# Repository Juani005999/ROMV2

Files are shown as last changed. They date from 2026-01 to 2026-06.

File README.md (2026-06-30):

# ROMV2 / SQM Lite

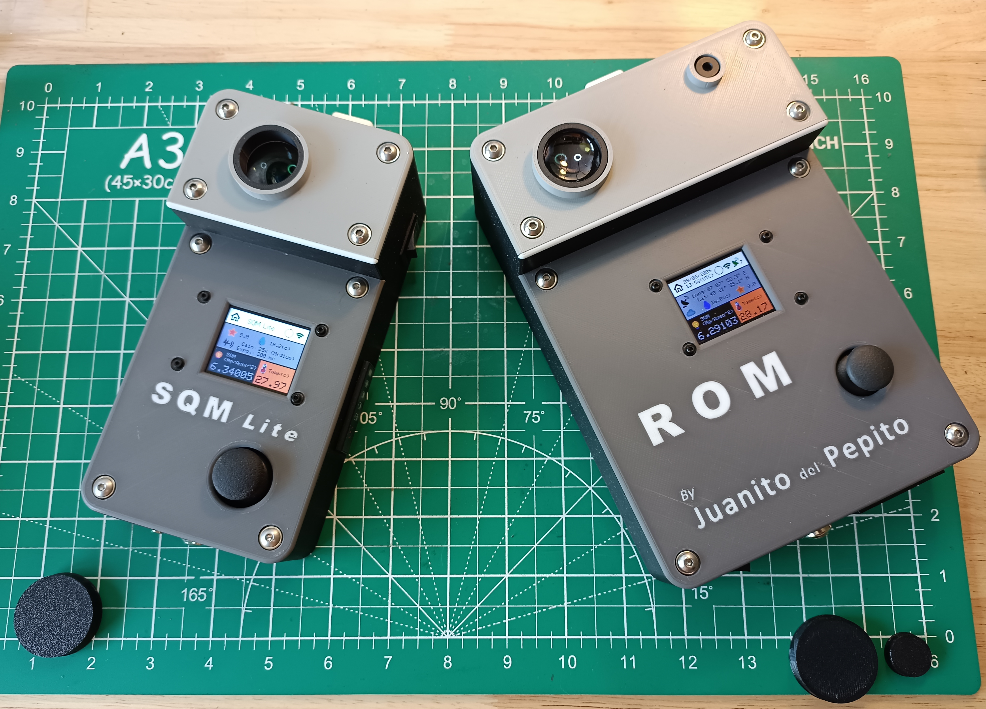
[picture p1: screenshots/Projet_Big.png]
ROM V2 et SQM Lite


## Sommaire
- [Description](#description)
    - [Fonctionnalités](#fonctionnalités)
    - [Modèles](#modèles)
        - [Fonctionnalités par modèle](#fonctionnalités-par-modèle)
        - [Écrans disponibles](#écrans-disponibles)
    - [Echelle de Bortle](#echelle-de-bortle)
- [Liste des pièces](#liste-des-pièces)
    - [Liste des pièces du ROMV2](#liste-des-pièces-du-romv2)
        - [Amazon](#amazon)
        - [Ali Express](#ali-express)
        - [Visserie & Divers](#visserie--divers)
    - [Liste des pièces du SQMLite](#liste-des-pièces-du-sqmlite)
        - [Amazon](#amazon-1)
        - [Ali Express](#ali-express-1)
        - [Visserie & Divers](#visserie--divers-1)
- [Montage](#montage)
    - [Montage du ROMV2](#montage-du-romv2)
        - [Breadboard](#breadboard)
        - [PCB](#pcb)
        - [ESP32](#esp32)
        - [Capteurs](#capteurs)
    - [Montage du SQMLite](#montage-du-sqmlite)
        - [Breadboard](#breadboard-1)
        - [PCB](#pcb-1)
        - [ESP32](#esp32-1)
        - [Capteurs](#capteurs-1)
    - [Boxes](#boxes)
    - [Optique du TSL2591](#optique-du-tsl2591)
- [Firmware](#firmware)
    - [Bibliothèques nécessaires à l'application](#bibliothèques-nécessaires-à-lapplication)
    - [Sélection de la carte](#sélection-de-la-carte)
    - [Paramètres de l'application dans Arduino IDE](#paramètres-de-lapplication-dans-arduino-ide)
    - [Configuration de l'application](#configuration-de-lapplication)
    - [Configuration de l'écran TFT ST7735](#configuration-de-lécran-tft-st7735)
    - [Implémentation](#implémentation)
    - [Mode \"Debug\"](#mode-debug)
- [Utilisation](#utilisation)
    - [Matériel (ROMV2)](#matériel-romv2)
    - [Matériel (SQMLite)](#matériel-sqmlite)
    - [Navigation](#navigation)
    - [Mise en veille](#mise-en-veille)
    - [Logiciel](#logiciel)
        - [En-tête (ROMV2)](#en-tête-romv2)
        - [En-tête (SQMLite)](#en-tête-sqmlite)
        - [Ecran d'accueil](#ecran-daccueil)
        - [Ecran Luminosité](#ecran-luminosité)
        - [Ecran Environnement](#ecran-environnement)
        - [Ecran Ir Température](#ecran-ir-température)
        - [Ecran Niveaux](#ecran-niveaux)
        - [Ecran GPS](#ecran-gps)
        - [Ecran de calibration du capteur de luminosité TSL2591](#ecran-de-calibration-du-capteur-de-luminosité-tsl2591)
- [Driver ASCOM](#driver-ascom)
    - [Installation](#installation)
    - [Détection du périphérique bluetooth dans Windows](#détection-du-périphérique-bluetooth-dans-windows)
    - [Utilisation dans NINA](#utilisation-dans-nina)
        - [Sélection du ROM V2 dans NINA](#sélection-du-rom-v2-dans-nina)
        - [Première utilisation dans NINA](#première-utilisation-dans-nina)
- [Retex](#retex)
- [Révisions](#révisions)

## Description
Le **ROMV2** est un Sky Quality Meter (SQM) DIY (Do It Yourself) contenant les composants suivant :
- TSL2591
- MLX90614
- BME280
- ADXL345
- GPS NEO 8M
- TFT ST7735

Le **SQMLite** est un Sky Quality Meter (SQM) DIY (Do It Yourself) contenant les composants suivant :
- TSL2591
- BME280
- TFT ST7735

Le **SQMLite** est une version à moindre coût, centrée sur la mesure de qualité du ciel (SQM / Bortle) et des conditions d'environnement, sans la partie état du ciel, niveau à bulle ni GPS.

<p align="right"><a href="#sommaire">Retour au sommaire</a></p>

### Fonctionnalités

- Lecture de la luminosité (full / ir / visible), calcul de la quantité de lux, du SQM et du Bortle.
- Lecture de la luminosité dans une tâche dédiée FreeRTOS s'exécutant en paralèlle sur le 2ème coeur de l'ESP 32.
- Correction thermique de la lecture de la luminosité avec la température ambiante.
- Moyenne mobile du lux sur 50 valeurs permettant de réduire l'incertitude mesurée. Calcul du SQM et du Bortle sur la moyenne mobile du lux.
- Possibilité de remise à zéro de la moyenne mobile.
- Réglage automatique de la sensibilité (1x, 25x, 428x, 9876x) et de la durée de mesure (100ms, 200ms, 300ms, 400ms, 500ms, 600ms) du capteur de luminosité TSL2591.
- (*) Lecture de la qualité du ciel (3 états : ciel clair / peu nuageux / nuageux) via le capteur MLX90614 permettant la lecture de la température du ciel.
- Lecture des conditions d'environnement (Température, taux d'humidité, pression atmosphérique) via le capteur BME280.
- Calcul du point de rosée.
- (*) Niveaux à bulle permettant de diriger l'optique vers le zénith grâce au capteur ADXL345.
- (*) Coordonnées GPS et Date/Heure UTC issues du capteur GPS NEO 8M.
- Connection Bluetooth BLE.
- Driver ASCOM permettant de se connecter via Bluetooth BLE.
- Connection Wifi et Broker MQTT.
- Indicateur de mesure de luminosité en cours.
- Indicateur d'état de connection Bluetooth BLE client / Wifi MQTT / Offline.
- (*) Indicateur d'état du GPS.
- Indicateur de charge restante dans la batterie.
- Mise en veille de l'écran après 5 minutes d'inactivité ou sur demande.
- Ecran de calibration du capteur de luminosité (TSL2591) avec sauvegarde et lecture de la calibration en EEPROM permettant de stocker cette valeur même après extinction de l'appareil.
- Ecran de sélection de la connection réseau : Bluetooth BLE / Wifi MQTT / Offline. Sauvegarde du paramètre en EEPROM.
- Ecran de paramétrage de la connection Wifi et Broker MQTT. Page web se connectant au périphérique et permettant la saisie des paramètres réseaux. Sauvegarde des paramètres réseaux en EEPROM.

(*) ***ROMV2*** uniquement

<p align="right"><a href="#sommaire">Retour au sommaire</a></p>

### Modèles

#### Fonctionnalités par modèle
| Composant / Fonction | ROMV2 | SQMLite |
| --- | :---: | :---: |
| TSL2591 — Luminosité / SQM / Bortle | ✅ | ✅ |
| BME280 — Environnement / point de rosée | ✅ | ✅ |
| TFT ST7735 — Affichage | ✅ | ✅ |
| MLX90614 — État du ciel (IR) | ✅ | ❌ |
| ADXL345 — Niveau à bulle | ✅ | ❌ |
| GPS NEO 8M — Coordonnées / UTC | ✅ | ❌ |
| Connexion BLE + Driver ASCOM | ✅ | ✅ |
| WiFi / MQTT | ✅ | ✅ |

#### Écrans disponibles
| Écran | ROMV2 | SQMLite |
| --- | :---: | :---: |
| Accueil | ✅ | ✅ |
| Luminosité | ✅ | ✅ |
| Environnement | ✅ | ✅ |
| Ir Température | ✅ | ❌ |
| Niveaux | ✅ | ❌ |
| GPS | ✅ | ❌ |
| Sélection de la connection réseau | ✅ | ✅ |
| Paramétrage du Wifi MQTT | ✅ | ✅ |
| Calibration du capteur de luminosité TSL 2591 | ✅ | ✅ |

> [!TIP]
> Le choix du modèle se fait simplement en ouvrant le bon exemple dans l'Arduino IDE (***Fichier*** -> ***Exemples*** -> ***ROMV2*** -> ***ROMV2*** ou ***SQMLite***). La même bibliothèque et la même configuration `ROMV2_APP_CONFIG.h` servent les deux.

<p align="right"><a href="#sommaire">Retour au sommaire</a></p>

### Echelle de Bortle

Voici l'échelle de Bortle utilisée dans l'application.

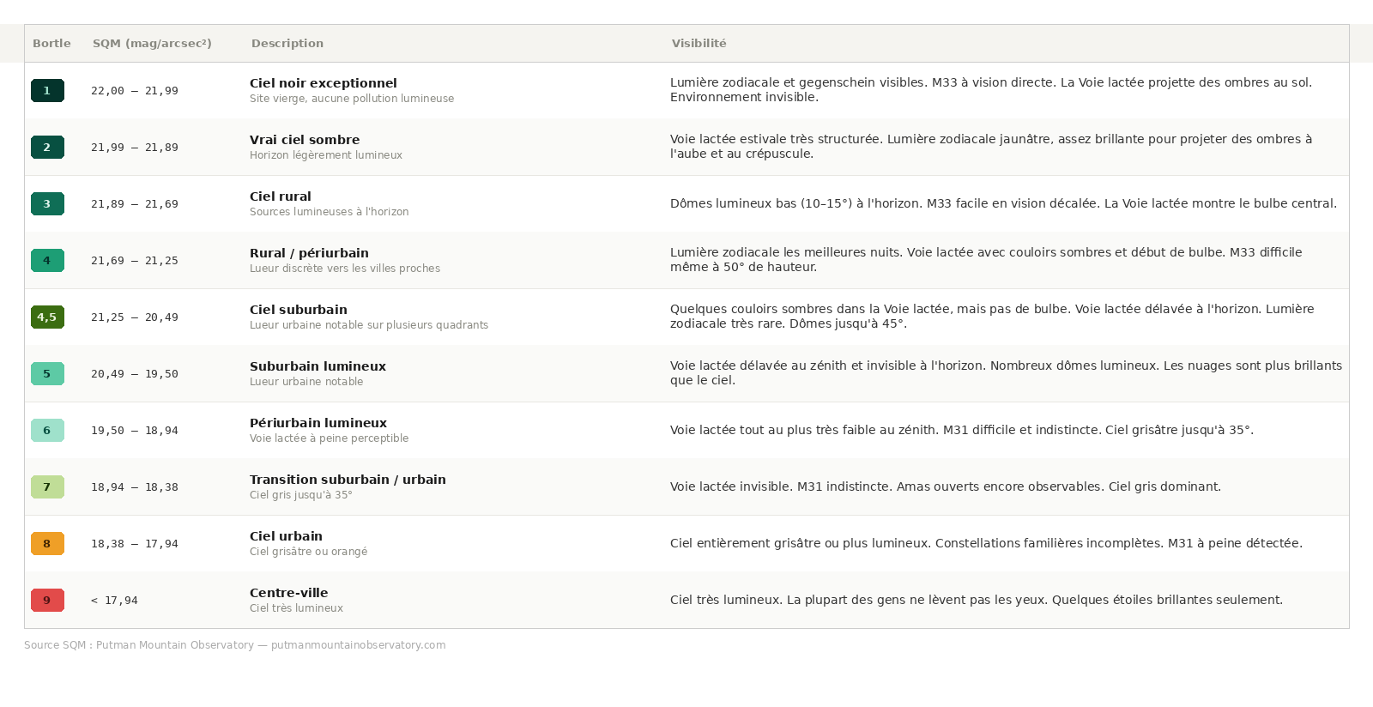
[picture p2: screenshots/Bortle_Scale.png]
Bortle Scale


<p align="right"><a href="#sommaire">Retour au sommaire</a></p>

## Liste des pièces
### Liste des pièces du ROMV2
#### Amazon

| Composant | Prix | Nb. pièces | Prix unitaire |
| --- | --- | --- | --- |
| [ESP32 with Battery (Micro USB)](https://www.amazon.fr/dp/B07YXFBFWF) | 18.77 € | 1 | 18.77 € |
| [TSL2591](https://www.amazon.fr/dp/B0GGD3FNKM) | 15.10 € | 1 | 15.10 € |
| [BME280](https://www.amazon.fr/dp/B07HMQMW6M) | 30.99 € | 5 | 6.20 € |
| [ADXL345](https://www.amazon.fr/ADXL345-Acc%C3%A9l%C3%A9rom%C3%A8tres-Acc%C3%A9l%C3%A9rom%C3%A8tre-Num%C3%A9rique-Transmission/dp/B0CMHXKVFK) | 10.56 € | 5 | 2.12 € |
| [MLX90614](https://www.amazon.fr/Fyearfly-Capteur-Temp%C3%A9rature-Infrarouge-MLX90614ESF/dp/B0CG9VL65J) | 33.49 € | 2 | 16.75 € |
| [GPS NEO 8M](https://www.amazon.fr/ElectroWorldFR-Module-NEO-8M-antenne-c%C3%A9ramique/dp/B09TX372XH) | 20.99 € | 1 | 20.99 € |
| [TFT ST7735](https://www.amazon.fr/AZDelivery-TFT-Compatible-Raspberry-incluant/dp/B07TJGF8HS) | 27.99 € | 5 | 5.60 € |
| [Lentille D23 F30](https://www.amazon.fr/Lentille-biconvexe-Double-Convexe-Optique/dp/B0GVHDZD22) | 25.94 € | 1 | 25.94 € |
| [Joystick](https://www.amazon.fr/Gebildet-Joystick-Commande-Contr%C3%B4leur-Raspberry/dp/B0DPMN19G6) | 10.99 € | 8 | 1.37 € |
| [Boot Button](https://www.amazon.fr/dp/B07S1MNB8C) | 10.99 € | 5 | 2.20 € |
| [Interrupteur à bascule](https://www.amazon.fr/dp/B076VKRKQQ) | 6.49 € | 5 | 1.30 € |
| [Rallonge Micro USB](https://www.amazon.fr/dp/B08HCTZ9P5) | 11.79 € | 2 | 5.90 € |
| [Testeur de capacité](https://www.amazon.fr/dp/B0DKHT664R) | 13.19 € | 4 | 3.30 € |
| | | Total | **125.54 €** |

<p align="right"><a href="#sommaire">Retour au sommaire</a></p>

#### Ali Express
| Composant | Prix | Nb. pièces | Prix unitaire |
| --- | --- | --- | --- |
| [ESP32 with Battery (Micro USB)](https://fr.aliexpress.com/item/1005007579177706.html) | 4.19 € | 1 | 4.19 € |
| [TSL2591](https://fr.aliexpress.com/item/1005009222536594.html) | 4.19 € | 1 | 4.19 € |
| [BME280](https://fr.aliexpress.com/item/1005010256393146.html) | 2.99 € | 1 | 2.99 € |
| [ADXL345](https://fr.aliexpress.com/item/1005007076396937.html) | 2.04 € | 1 | 2.04 € |
| [MLX90614](https://fr.aliexpress.com/item/32853499710.html) | 5.93 € | 1 | 5.93 € |
| [GPS NEO 8M](https://fr.aliexpress.com/item/1005006323393609.html) | 9.29 € | 1 | 9.29 € |
| [TFT ST7735](https://fr.aliexpress.com/item/1005008974306385.html) | 3.20 € | 1 | 3.20 € |
| [Lentille D23 F30](https://fr.aliexpress.com/item/1005007033633969.html) | 2.06 € | 1 | 2.06 € |
| [Joystick](https://fr.aliexpress.com/item/1005009009852719.html) | 0.51 € | 1 | 0.51 € |
| [Boot Button](https://fr.aliexpress.com/item/1005007876916629.html) | 6.69 € | 5 | 1.34 € |
| [Interrupteur à bascule](https://fr.aliexpress.com/item/1005010311259797.html) | 1.65 € | 10 | 0.17 € |
| [Rallonge Micro USB](https://fr.aliexpress.com/item/1005005292730047.html) | 1.09 € | 1 | 1.09 € |
| [Testeur de capacité](https://fr.aliexpress.com/item/1005006350742151.html) | 1.45 € | 1 | 1.45 € |
| | | Total | **38.45 €** |

<p align="right"><a href="#sommaire">Retour au sommaire</a></p>

#### Visserie & Divers

| Composant | Propriétés | Quantité |
| --- | --- | --- |
| Vis & rondelles | M4 x 20mm | 8 |
| Vis & rondelles | M2 x 20mm | 4 |
| Vis & rondelles | M2 x 8mm | 21 |
| Vis & rondelles | M2 x 6mm | 8 |
| Ecrou Nylstop autobloquants | M2 | 7 |
| Condensateur | 100 µF | 1 |
| Condensateur céramique | 100 nF | 1 |
| [PCB EPLZON](https://www.amazon.fr/dp/B0B5DCHM7K) | ... | 1 |
| [Câbles Dupont](https://www.amazon.fr/Breadboard-Jumper-Wires-Dupont-Cable/dp/B0BTT48V7P) | ... | ... |
| [PCB Vis Connecteur](https://www.amazon.fr/dp/B082ZNRQMJ?th=1) | ... | ... |
| [Jumper Breadboard](https://www.amazon.fr/dp/B0F6LJS4L2?ref=ppx_yo2ov_dt_b_fed_asin_title) | ... | ... |
| [Pile Rechargeable 18650](https://bestpiles.fr/piles-rechargeables-18650/991-pile-rechargeable-18650-inr18650mj1-li-ion-37v-3500mah-10a-8438493099829.html) | Li-ion 3,7V 3500mAh 10A | 1 |

<p align="right"><a href="#sommaire">Retour au sommaire</a></p>

### Liste des pièces du SQMLite
#### Amazon

| Composant | Prix | Nb. pièces | Prix unitaire |
| --- | --- | --- | --- |
| ESP32 with Battery (USB-C) | 18.77 € | 1 | 18.77 € |
| [TSL2591](https://www.amazon.fr/dp/B0GGD3FNKM) | 12.69 € | 1 | 12.69 € |
| [BME280](https://www.amazon.fr/dp/B07HMQMW6M) | 39.48 € | 5 | 7.90 € |
| [TFT ST7735](https://www.amazon.fr/AZDelivery-TFT-Compatible-Raspberry-incluant/dp/B07TJGF8HS) | 27.99 € | 5 | 5.60 € |
| [Lentille D23 F30](https://www.amazon.fr/Lentille-biconvexe-Double-Convexe-Optique/dp/B0GVHDZD22) | 25.94 € | 1 | 25.94 € |
| [Joystick](https://www.amazon.fr/Gebildet-Joystick-Commande-Contr%C3%B4leur-Raspberry/dp/B0DPMN19G6) | 10.99 € | 8 | 1.37 € |
| [Boot Button](https://www.amazon.fr/dp/B07S1MNB8C) | 10.99 € | 5 | 2.20 € |
| [Interrupteur à bascule](https://www.amazon.fr/dp/B076VKRKQQ) | 7.49 € | 5 | 1.50 € |
| [Rallonge USB-C](https://www.amazon.fr/Cablecc-3-1-type-femelle-donn%C3%A9es-dextension/dp/B075P2FF7L) | 17.56 € | 1 | 17.56 € |
| [Testeur de capacité](https://www.amazon.fr/dp/B0DKHT664R) | 12.79 € | 4 | 3.20 € |
| | | Total | **96.73 €** |

<p align="right"><a href="#sommaire">Retour au sommaire</a></p>

#### Ali Express
| Composant | Prix | Nb. pièces | Prix unitaire |
| --- | --- | --- | --- |
| [ESP32 with Battery (USB-C)](https://fr.aliexpress.com/item/1005007579177706.html) | 5.09 € | 1 | 5.09 € |
| [TSL2591](https://fr.aliexpress.com/item/1005009222536594.html) | 3.79 € | 1 | 3.79 € |
| [BME280](https://fr.aliexpress.com/item/1005010256393146.html) | 4.59 € | 1 | 4.59 € |
| [TFT ST7735](https://fr.aliexpress.com/item/1005008974306385.html) | 3.29 € | 1 | 3.29 € |
| [Lentille D23 F30](https://fr.aliexpress.com/item/1005007033633969.html) | 2.33 € | 1 | 2.33 € |
| [Joystick](https://fr.aliexpress.com/item/1005009009852719.html) | 0.46 € | 1 | 0.46 € |
| [Boot Button](https://fr.aliexpress.com/item/1005007876916629.html) | 26.19 € | 20 | 1.31 € |
| [Interrupteur à bascule](https://fr.aliexpress.com/item/1005010311259797.html) | 1.79 € | 10 | 0.18 € |
| [Rallonge USB-C 0.2m](https://fr.aliexpress.com/item/1005005292730047.html) | 1.71 € | 1 | 1.71 € |
| [Testeur de capacité](https://fr.aliexpress.com/item/1005006350742151.html) | 1.45 € | 1 | 1.45 € |
| | | Total | **24.20 €** |

<p align="right"><a href="#sommaire">Retour au sommaire</a></p>

#### Visserie & Divers
| Composant | Propriétés | Quantité |
| --- | --- | --- |
| Vis & rondelles | M4 x 20mm | 8 |
| Vis & rondelles | M2 x 20mm | 4 |
| Vis & rondelles | M2 x 8mm | 21 |
| Vis & rondelles | M2 x 6mm | 8 |
| Ecrou Nylstop autobloquants | M2 | 7 |
| [PCB EPLZON](https://www.amazon.fr/dp/B0B5DCHM7K) | ... | 1 |
| [Câbles Dupont](https://www.amazon.fr/Breadboard-Jumper-Wires-Dupont-Cable/dp/B0BTT48V7P) | ... | ... |
| [PCB Vis Connecteur](https://www.amazon.fr/dp/B082ZNRQMJ?th=1) | ... | ... |
| [Jumper Breadboard](https://www.amazon.fr/dp/B0F6LJS4L2?ref=ppx_yo2ov_dt_b_fed_asin_title) | ... | ... |
| [Pile Rechargeable 18650](https://bestpiles.fr/piles-rechargeables-18650/991-pile-rechargeable-18650-inr18650mj1-li-ion-37v-3500mah-10a-8438493099829.html) | Li-ion 3,7V 3500mAh 10A | 1 |

<p align="right"><a href="#sommaire">Retour au sommaire</a></p>

## Montage

### Montage du ROMV2

Montage
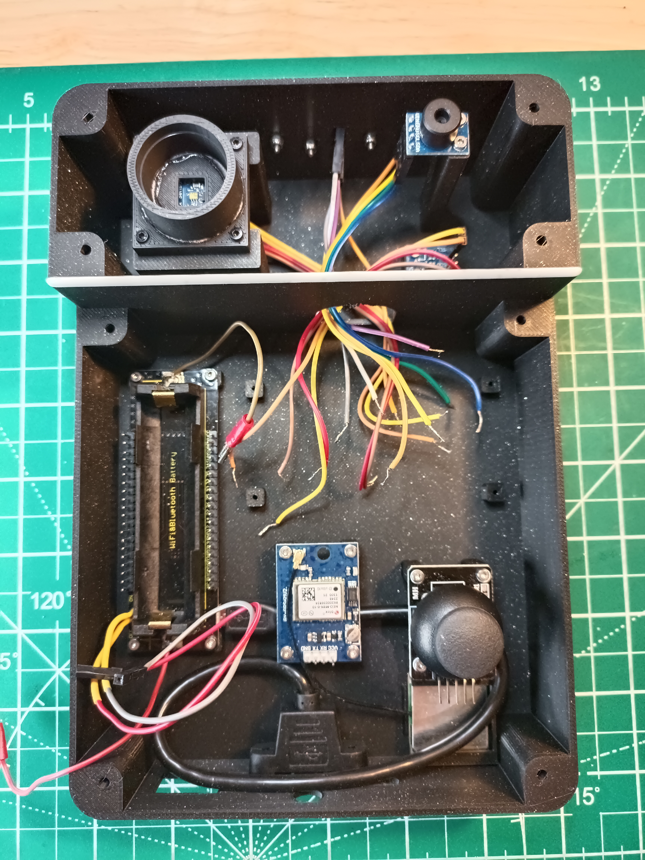
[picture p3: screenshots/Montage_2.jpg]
Montage


<p align="right"><a href="#sommaire">Retour au sommaire</a></p>

#### Breadboard
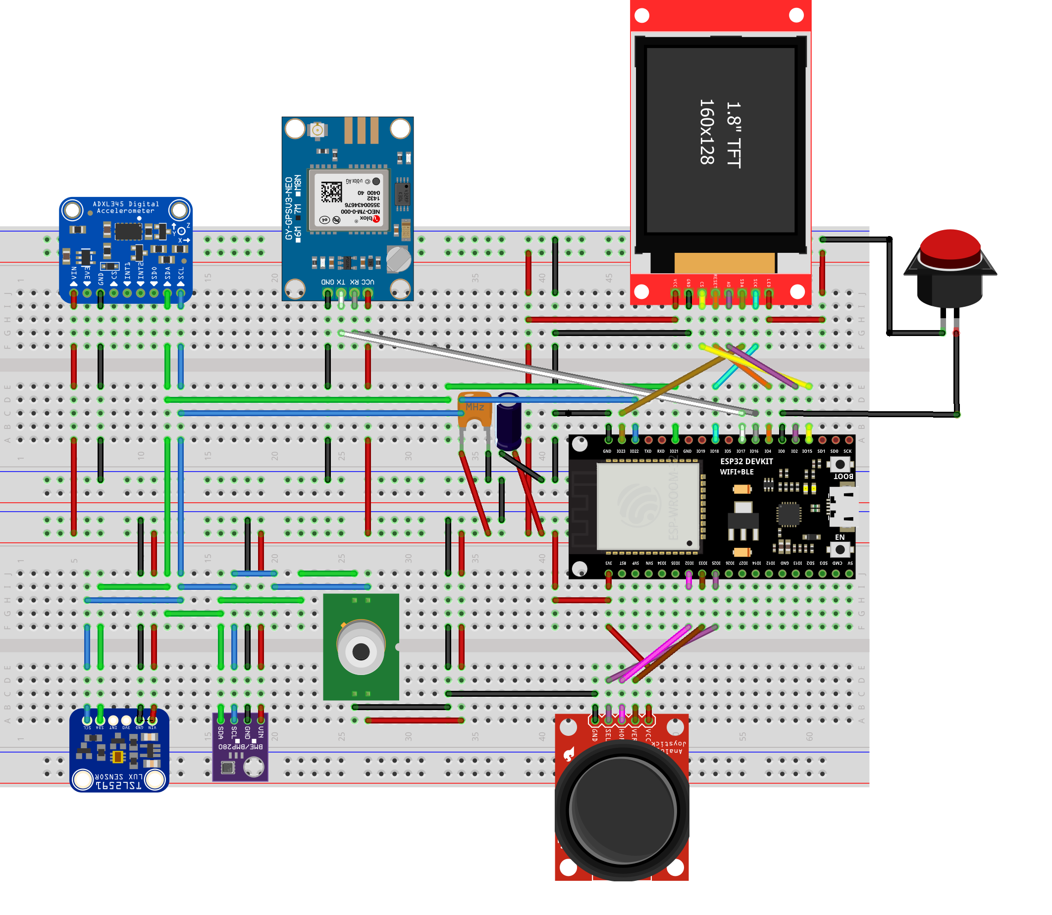
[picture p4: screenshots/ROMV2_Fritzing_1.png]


<p align="right"><a href="#sommaire">Retour au sommaire</a></p>

#### PCB
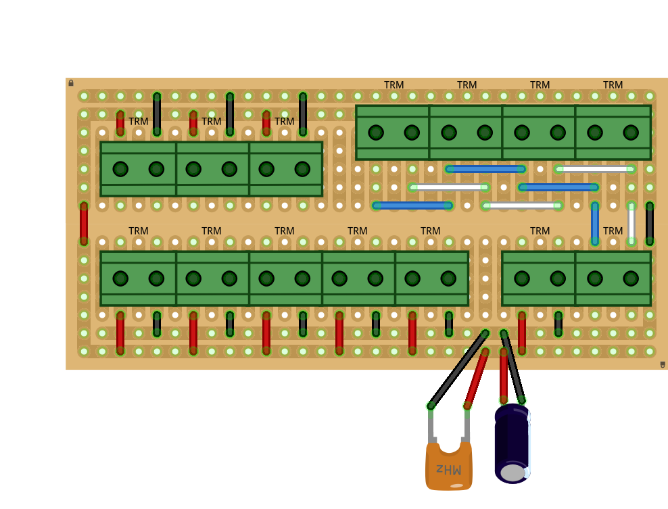
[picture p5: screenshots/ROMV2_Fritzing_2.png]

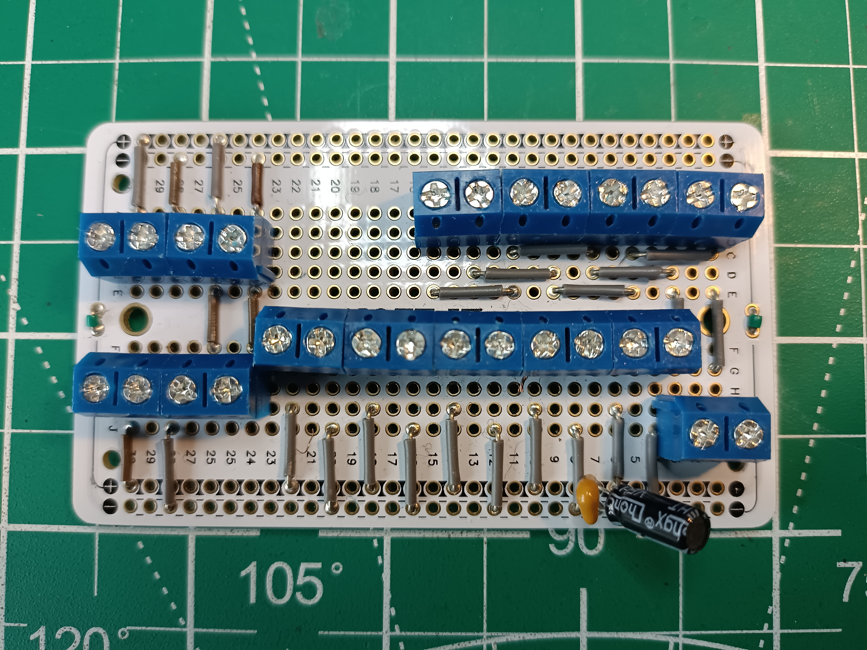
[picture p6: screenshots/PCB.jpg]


<p align="right"><a href="#sommaire">Retour au sommaire</a></p>

#### ESP32
Des branchements direct sur l'ESP32 sont nécessaires :
- 2 câbles Dupont branchés directement sur l'interrupteur de l'ESP et connectés à l'interrupteur du ROM.
- 2 câbles branchés sur les pôles + et - de l'ESP et connectés à l'indicateur de charge restante de la batterie.

ESP32

> [!WARNING]
> Attention, le connecteur **micro USB** présent sur l'ESP est **très très fragile** (j'en ai personnellement cassé plusieurs sur d'autres projets en faisant des branchements). Je vous conseil donc de rajouter 2 points de soudure de part et d'autre du connecteur  afin d'augmenter sa solidité.

<p align="right"><a href="#sommaire">Retour au sommaire</a></p>

#### Capteurs
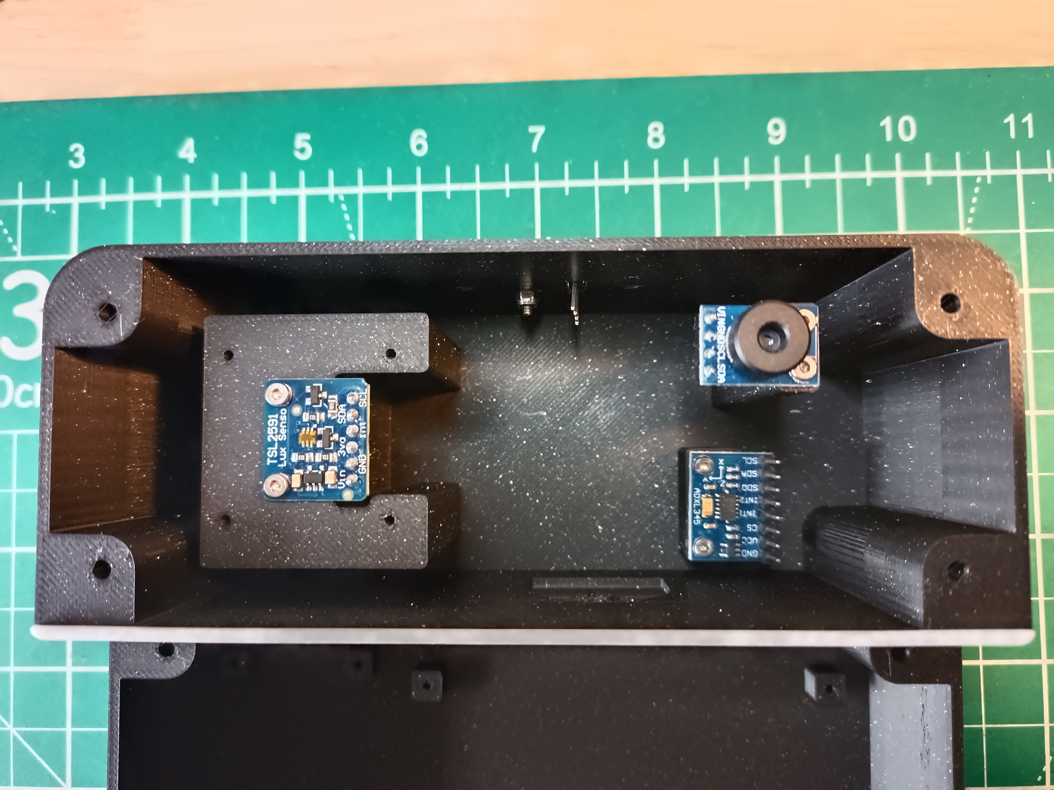
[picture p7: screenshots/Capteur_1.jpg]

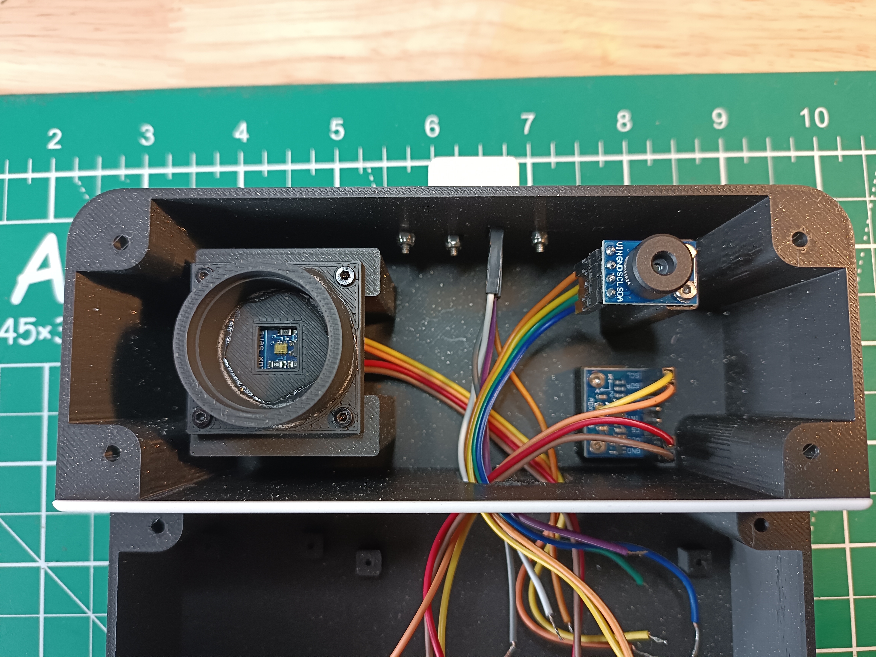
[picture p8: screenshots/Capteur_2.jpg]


<p align="right"><a href="#sommaire">Retour au sommaire</a></p>

### Montage du SQMLite
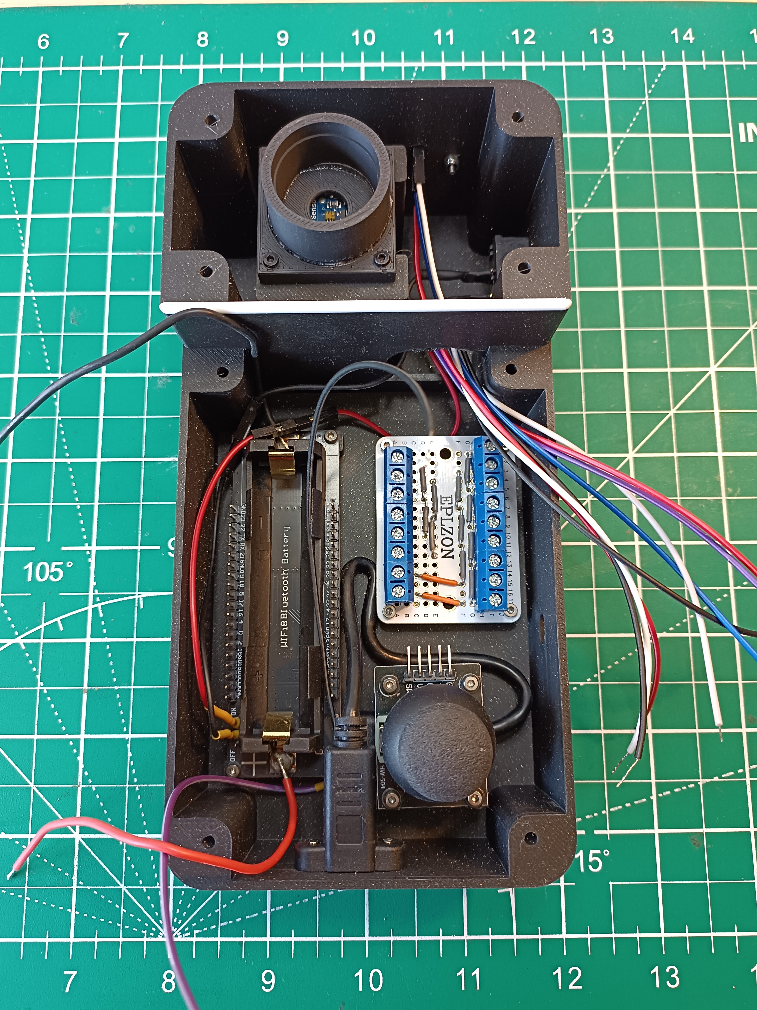
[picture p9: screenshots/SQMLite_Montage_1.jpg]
Montage


<p align="right"><a href="#sommaire">Retour au sommaire</a></p>

#### Breadboard
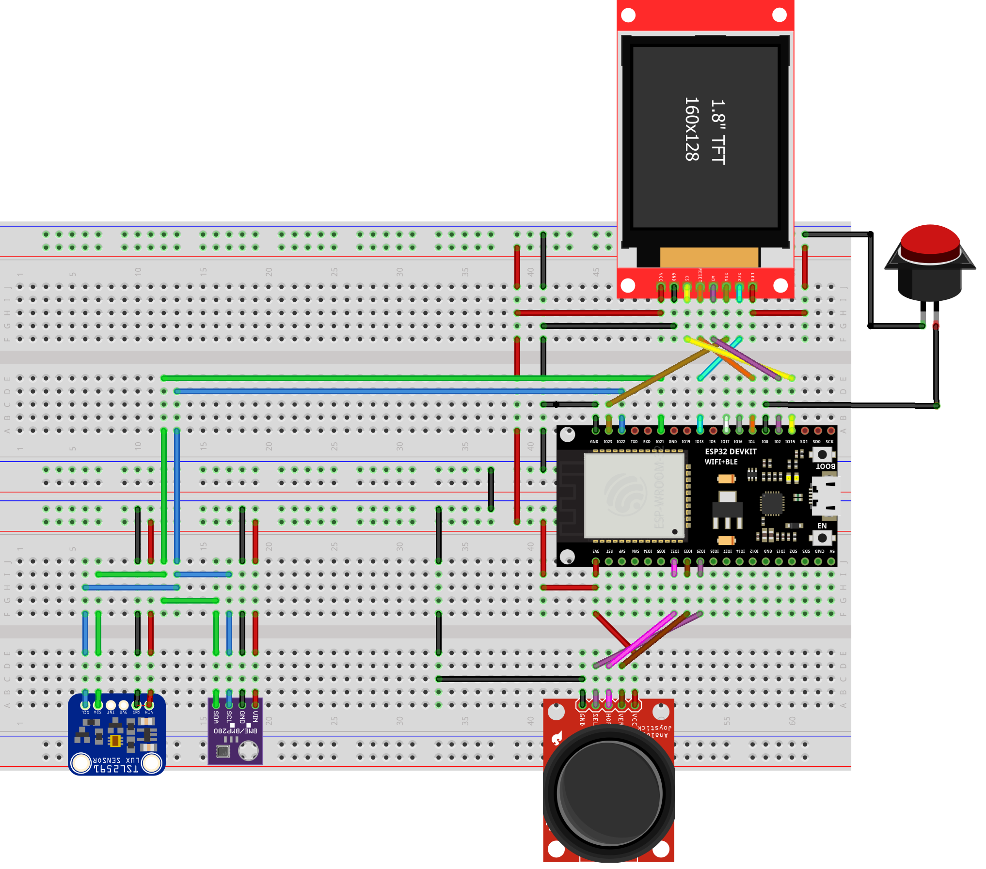
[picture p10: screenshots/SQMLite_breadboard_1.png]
Breadboard


<p align="right"><a href="#sommaire">Retour au sommaire</a></p>

#### PCB
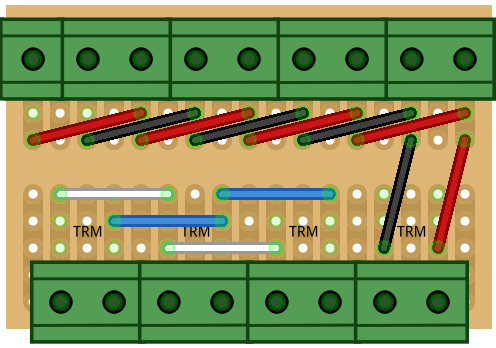
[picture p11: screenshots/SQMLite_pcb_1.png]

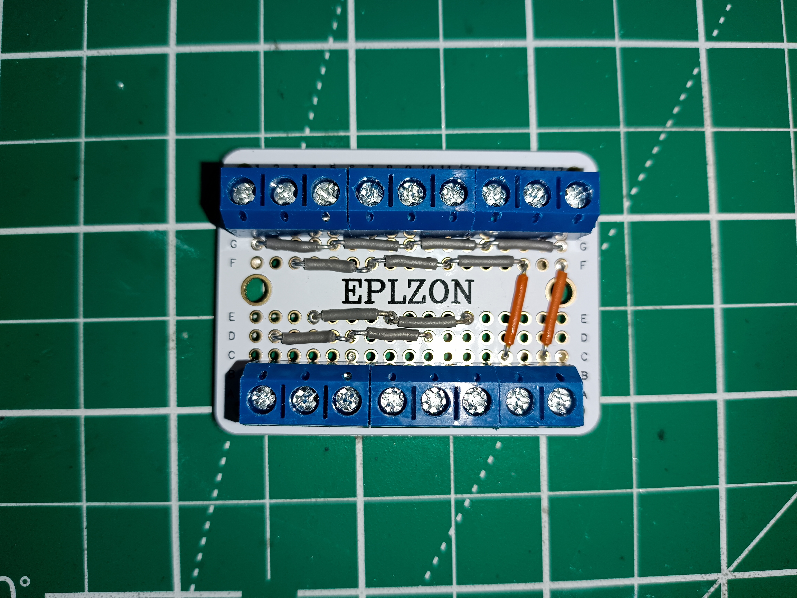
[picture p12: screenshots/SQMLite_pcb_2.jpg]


<p align="right"><a href="#sommaire">Retour au sommaire</a></p>

#### ESP32
Des branchements direct sur l'ESP32 sont nécessaires :
- 2 câbles Dupont branchés directement sur l'interrupteur de l'ESP et connectés à l'interrupteur du **SQM Lite**.
- 2 câbles branchés sur les pôles + et - de l'ESP et connectés à l'indicateur de charge restante de la batterie.

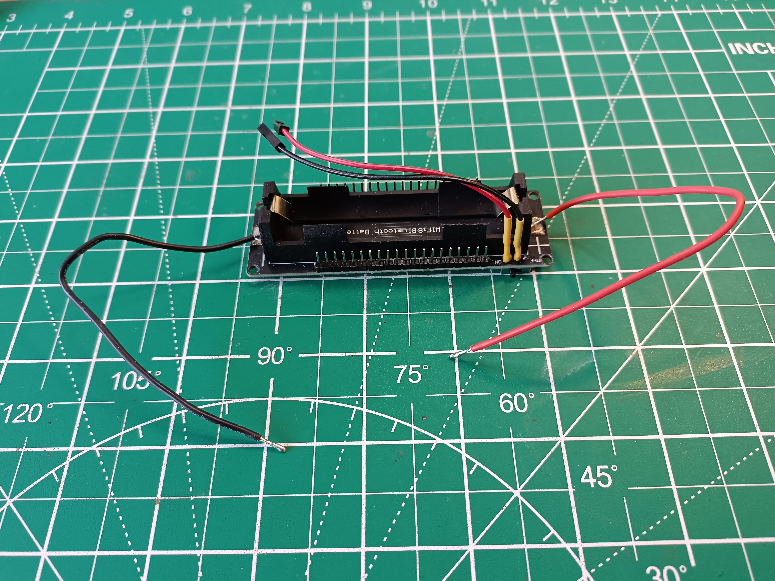
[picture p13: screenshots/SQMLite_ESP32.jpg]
ESP32


> [!WARNING]
> Attention, le connecteur **USB-C** présent sur l'ESP est **très très fragile** (j'en ai personnellement cassé plusieurs sur d'autres projets en faisant des branchements). Je vous conseil donc de rajouter 2 points de soudure de part et d'autre du connecteur  afin d'augmenter sa solidité.

<p align="right"><a href="#sommaire">Retour au sommaire</a></p>

#### Capteurs
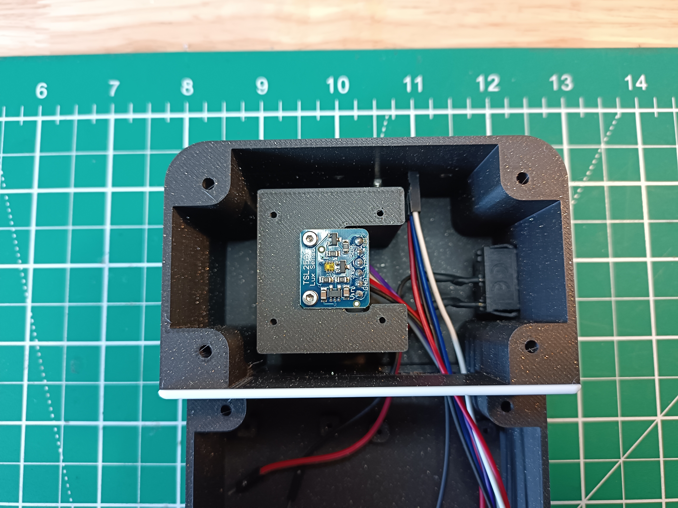
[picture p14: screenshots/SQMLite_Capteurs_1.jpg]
Capteurs

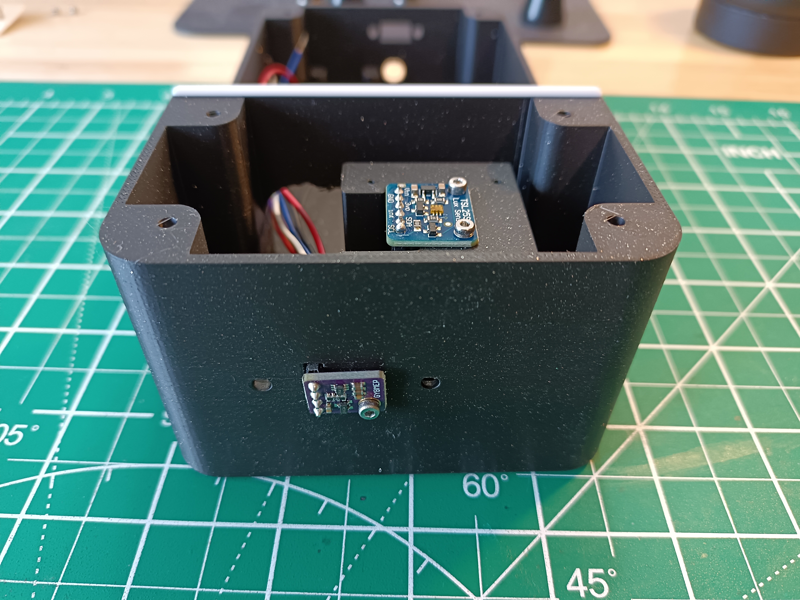
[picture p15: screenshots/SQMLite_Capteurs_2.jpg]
Capteurs

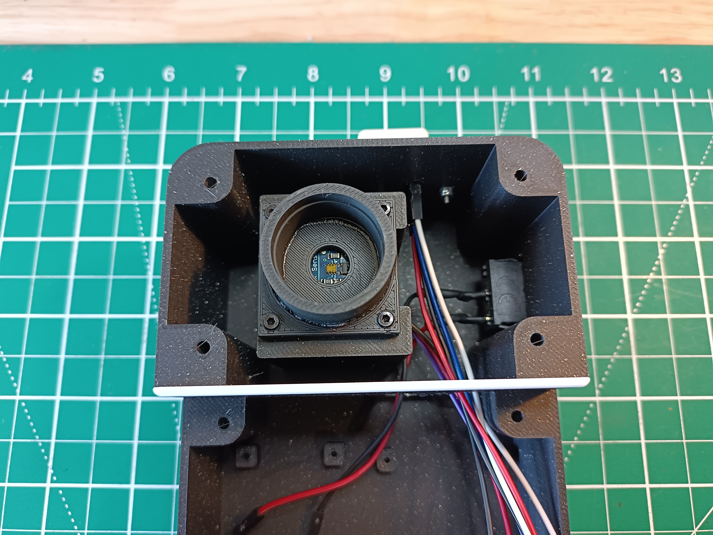
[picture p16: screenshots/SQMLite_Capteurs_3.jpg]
Capteurs

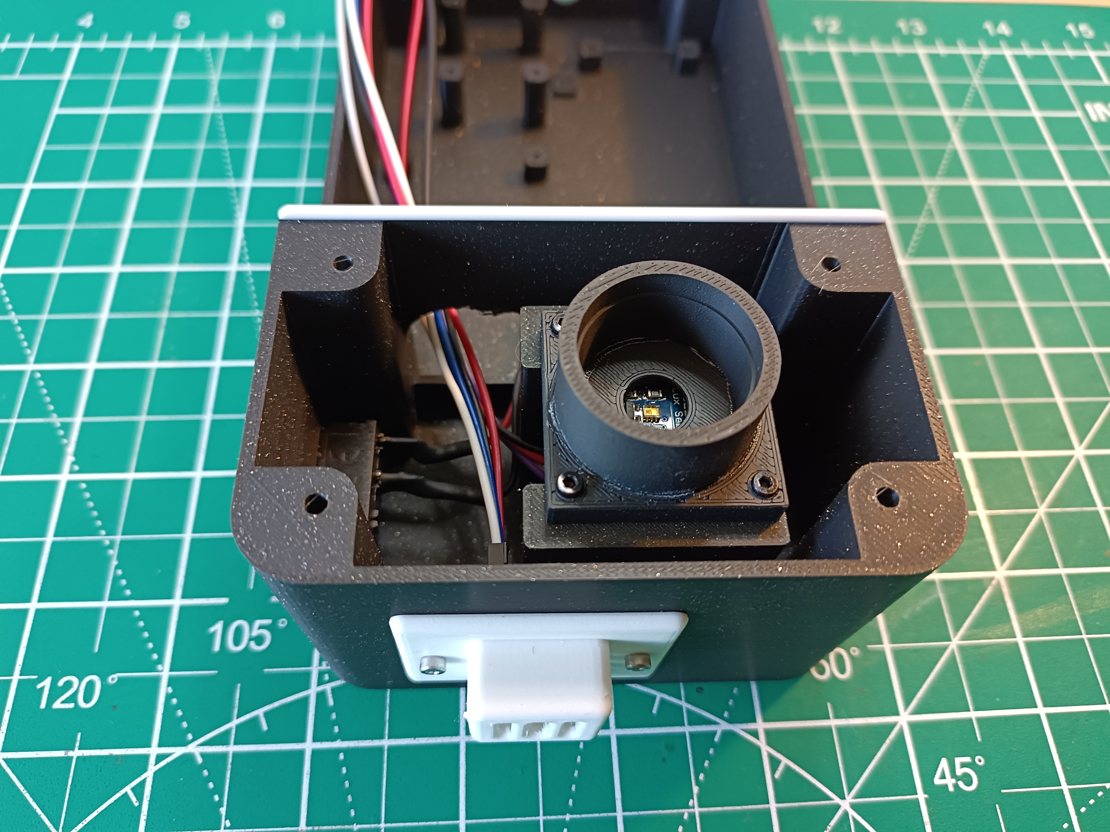
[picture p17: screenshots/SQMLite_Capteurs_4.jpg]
Capteurs


<p align="right"><a href="#sommaire">Retour au sommaire</a></p>

### Boxes
Vous trouverez dans [ce dossier](./Boxes/) tous les fichiers STL nécessaires à l'impression 3D.

<p align="right"><a href="#sommaire">Retour au sommaire</a></p>

### Optique du TSL2591
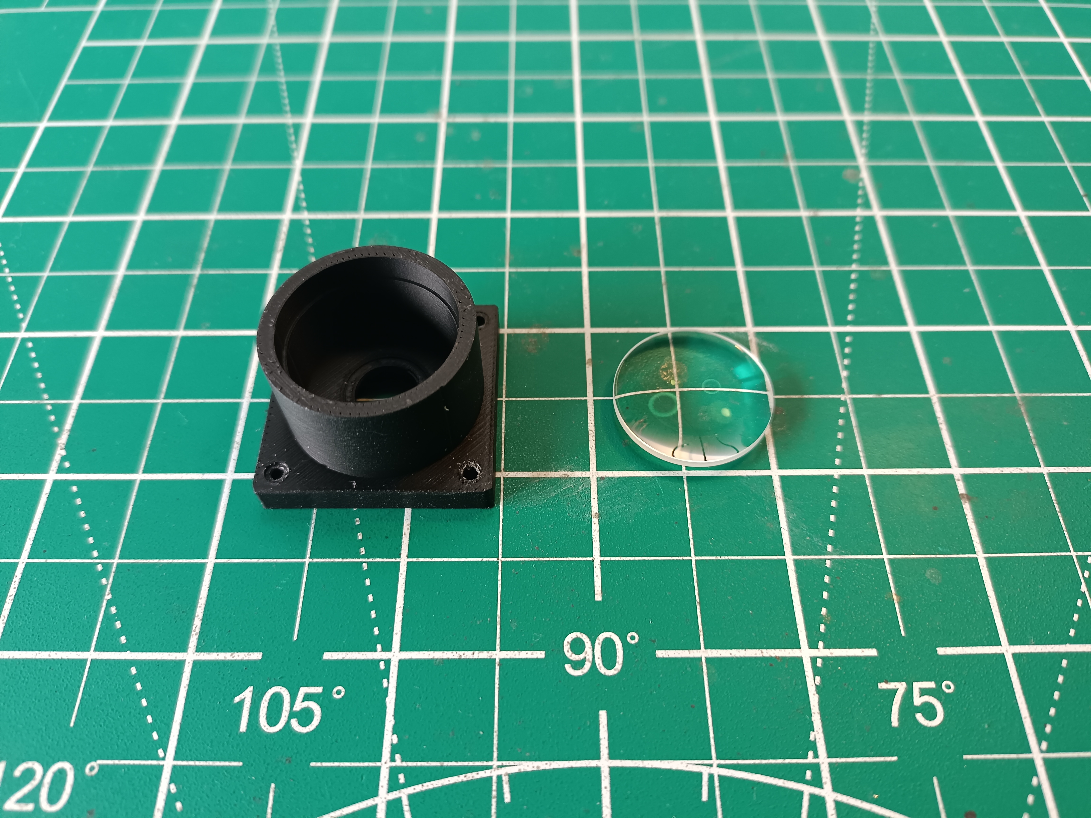
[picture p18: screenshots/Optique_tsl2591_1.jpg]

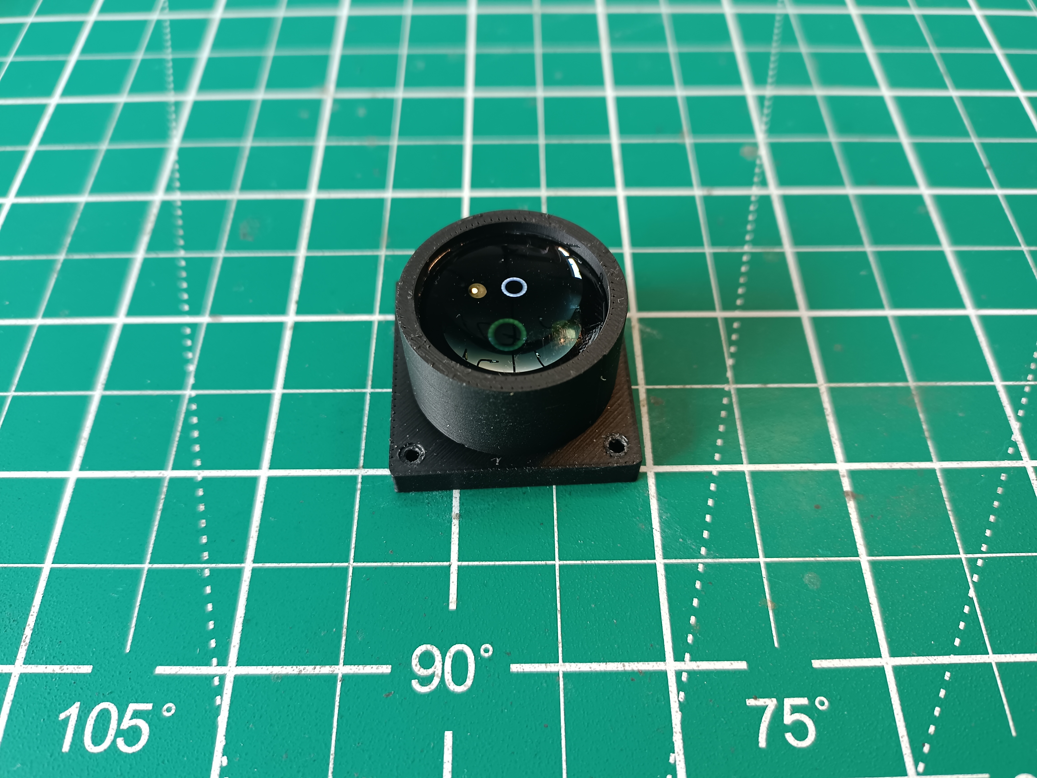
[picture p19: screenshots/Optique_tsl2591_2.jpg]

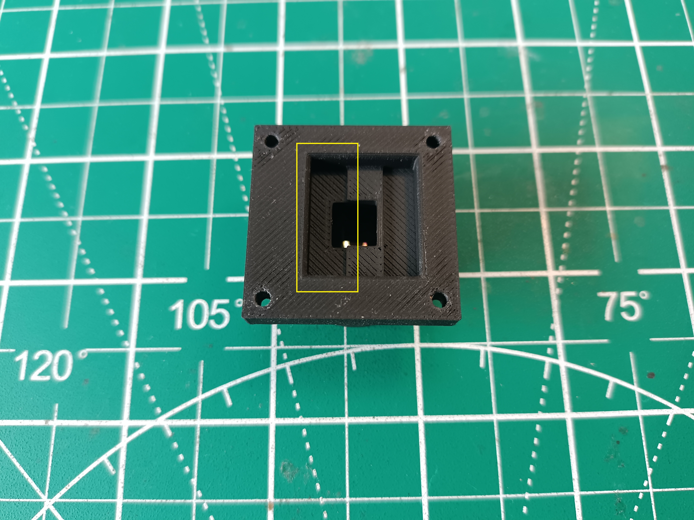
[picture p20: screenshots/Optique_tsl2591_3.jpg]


> [!IMPORTANT]
> La partie encadrée en jaune correspond au côté des vis du TSL2591.

> [!TIP]
> La lentille est optionnelle. Vous pouvez uniquement positionner le cache du capteur et le tube sans la lentille. Vous pourrez ensuite corriger la [calibration](#calibration) si nécessaire.

<p align="right"><a href="#sommaire">Retour au sommaire</a></p>

## Firmware

- Télécharger le fichier **ROMV2_Firmware.zip**
- Depuis votre Arduino IDE, installer la bibliothèque **ROMV2**, en sélectionnant le fichier téléchargé via le menu : \
***Croquis*** -> ***Importer une bibliothèque*** -> ***Ajouter la bibliothèque .ZIP ...***

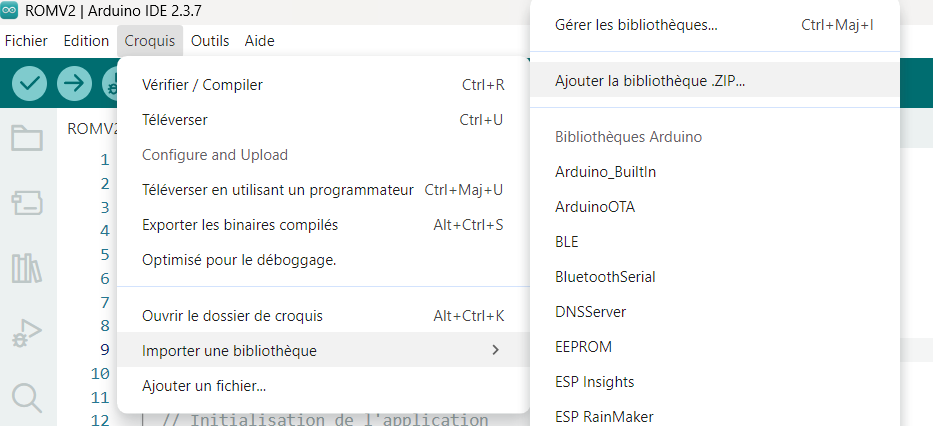
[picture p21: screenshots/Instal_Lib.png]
ROMV2_LIB


<p align="right"><a href="#sommaire">Retour au sommaire</a></p>

### Bibliothèques nécessaires à l'application
Voici la liste des bibliothèques utilisées par l'application que vous devez installer via le gestionnaire de librairies dans votre *Arduino IDE* :

- Adafruit_TSL2591
- Adafruit_BME280
- Adafruit_MLX90614
- Adafruit_ADXL345
- TFT_eSPI

<p align="right"><a href="#sommaire">Retour au sommaire</a></p>

### Sélection de la carte
Dans votre *Arduino IDE*, sélectionnez la carte **ESP32 Dev Module**.
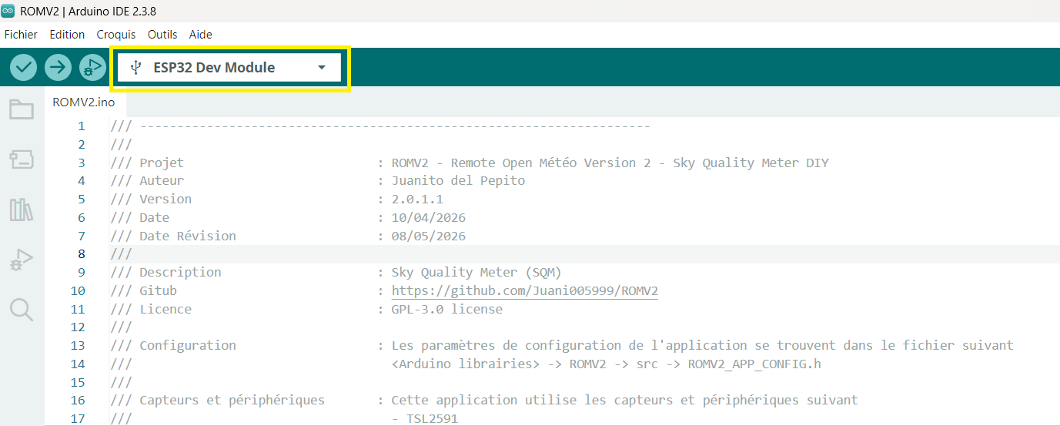
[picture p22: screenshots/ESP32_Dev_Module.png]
ESP32 Dev Module


<p align="right"><a href="#sommaire">Retour au sommaire</a></p>

### Paramètres de l'application dans Arduino IDE

> [!WARNING]
> Attention : l'application nécessite de se positionner en mode **"Huge App"** (cf. image ci-dessous), permettant ainsi de disposer de l'espace mémoire suffisant pour le fonctionnement sur l'ESP32.

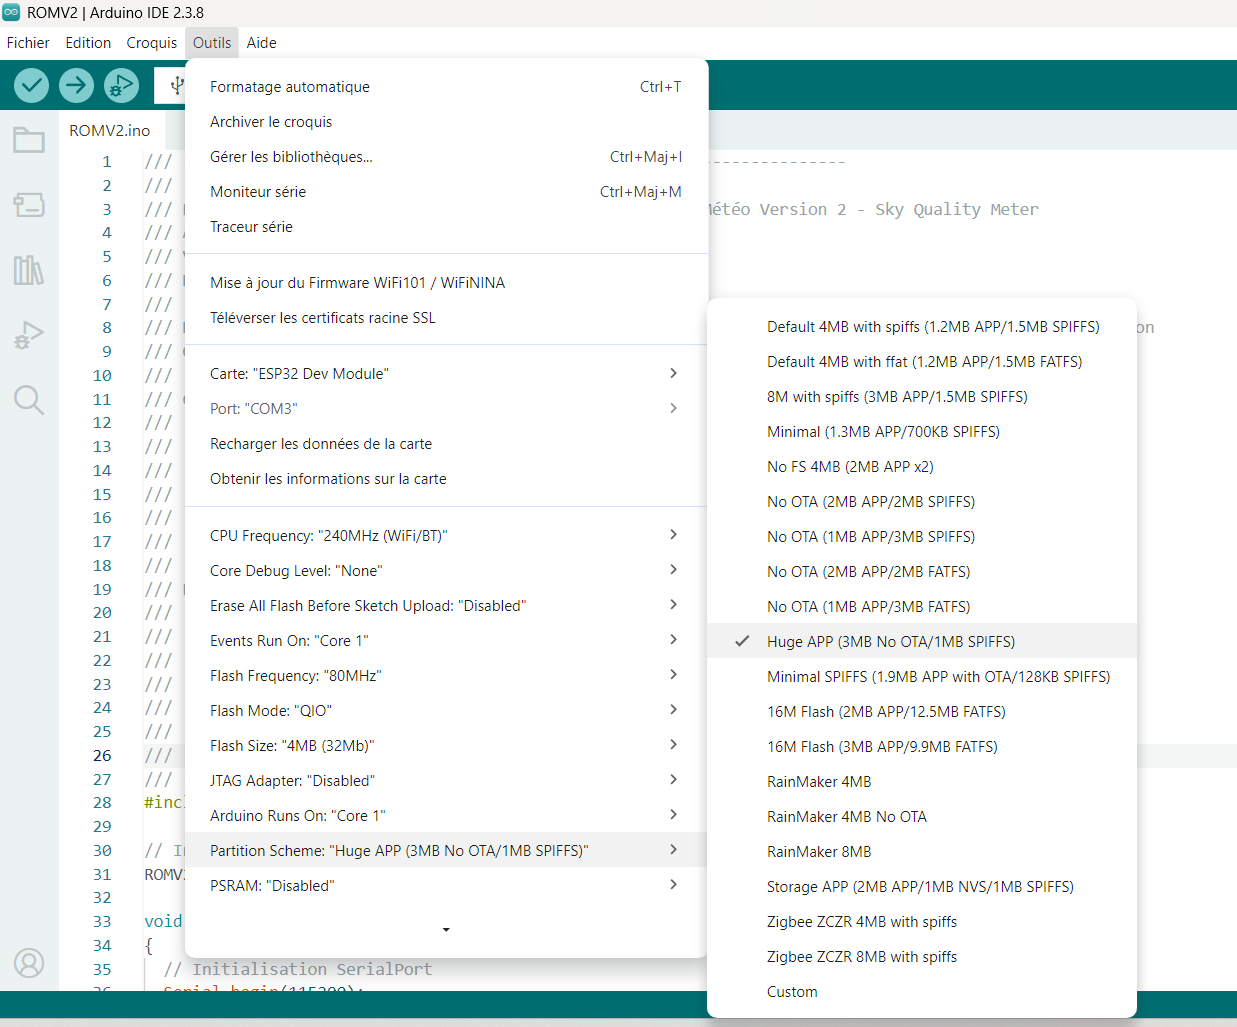
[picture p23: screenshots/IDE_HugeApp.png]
Arduino IDE Huge App


<p align="right"><a href="#sommaire">Retour au sommaire</a></p>

### Configuration de l'application
Vous pouvez accéder à la configuration de l'application via le fichier suivant : \
\<***Arduino librairies***\> -> ***ROMV2*** -> ***src*** -> ***ROMV2_APP_CONFIG.h***

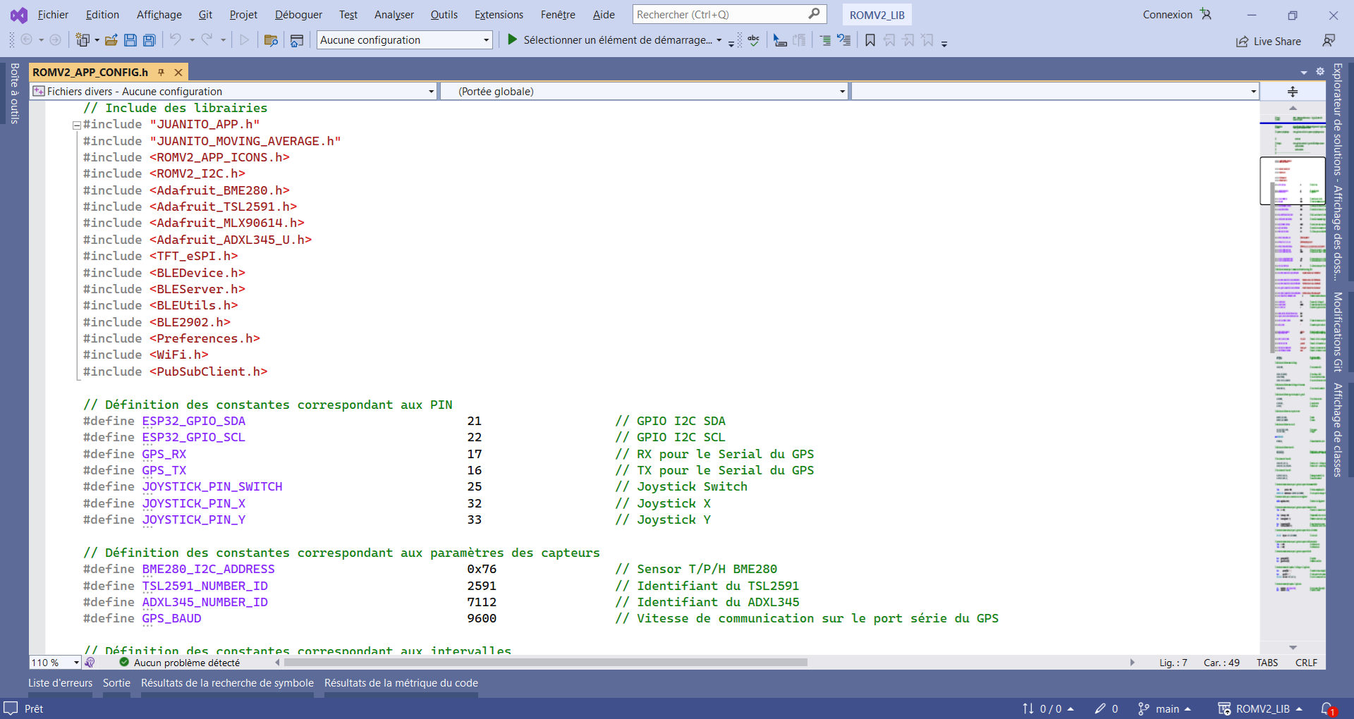
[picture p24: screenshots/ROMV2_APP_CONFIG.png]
ROMV2_APP_CONFIG.h


<p align="right"><a href="#sommaire">Retour au sommaire</a></p>

### Configuration de l'écran TFT ST7735
Afin de faire fonctionner votre écran, il vous sera nécessaire de le configurer via la bibliothèque **TFT_eSPI** en modifiant le fichier suivant : \
\<***Arduino librairies***\> -> ***TFT_sSPI*** -> ***User_Setup.h***

Vous devez modifier 2 paramètres :

- La sélection de votre écran :
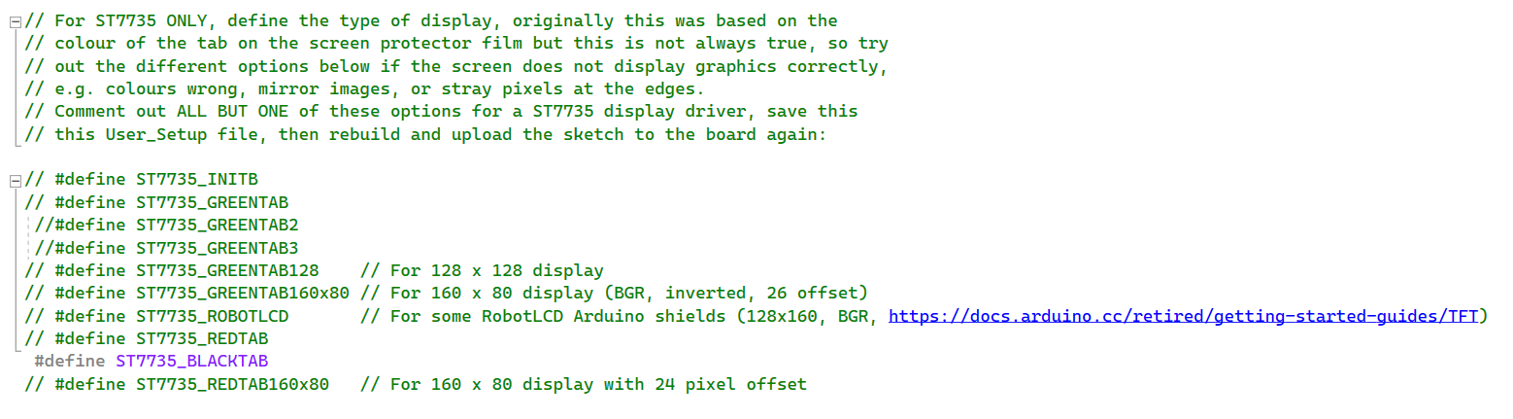
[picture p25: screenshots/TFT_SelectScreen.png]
TFT_eSPI Select Screen

- Les PINs associés à votre écran :
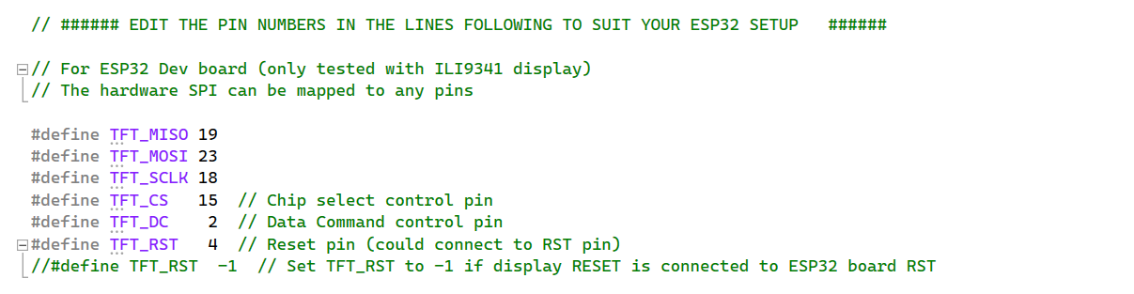
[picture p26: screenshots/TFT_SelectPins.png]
TFT_eSPI Select PINs


<p align="right"><a href="#sommaire">Retour au sommaire</a></p>

### Implémentation
Pour démarrer un nouveau projet **ROMV2**, il vous suffit d'aller dans les examples de votre Arduino IDE, et de sélectionner ***ROMV2*** -> ***ROMV2***.

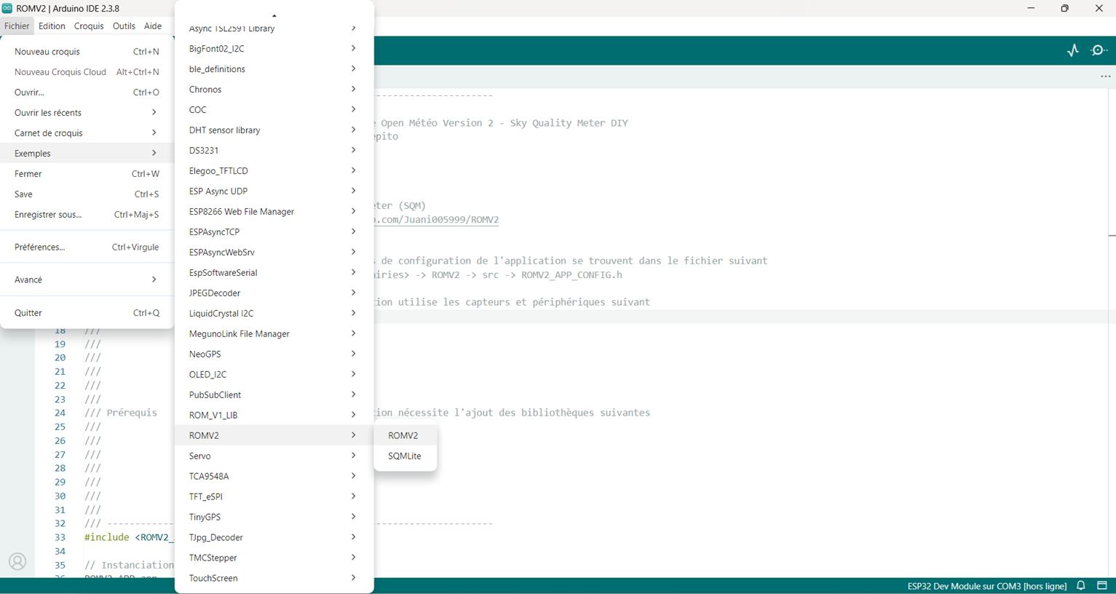
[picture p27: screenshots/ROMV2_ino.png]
ROMV2 Application example


Pour démarrer un nouveau projet **SQMLite**, il vous suffit d'aller dans les examples de votre Arduino IDE, et de sélectionner ***ROMV2*** -> ***SQMLite***.

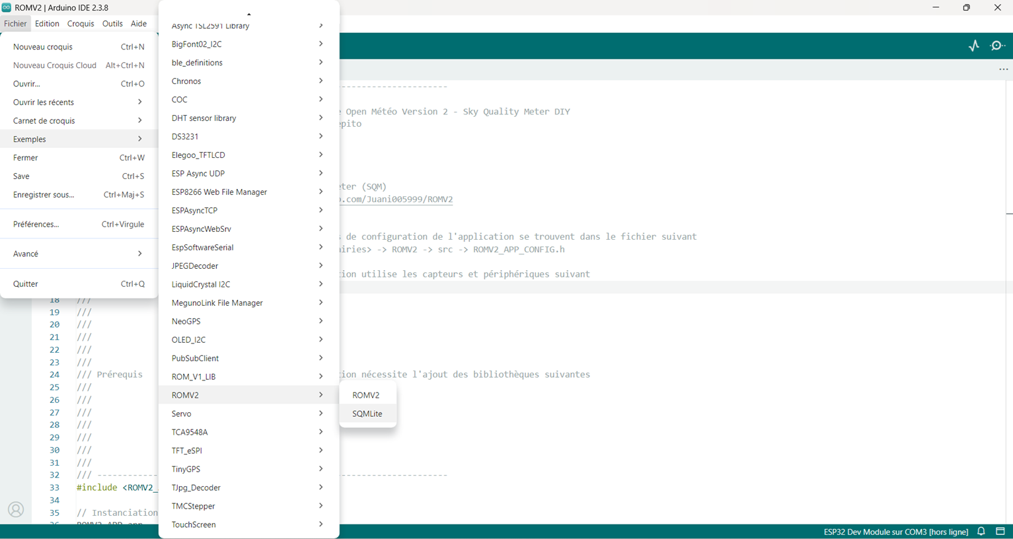
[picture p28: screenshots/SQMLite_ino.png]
SQMLite Application example


<p align="right"><a href="#sommaire">Retour au sommaire</a></p>

### Mode \"Debug\"
Pendant le développement de votre projet, vous pouvez activer le mode **Debug**.

> [!WARNING]
> Afin d'améliorer les performances, **n'oubliez pas de le désactiver une fois le fois le projet abouti**.

Dans le fichier suivant : \
\<***Arduino librairies***\> -> ***ROMV2*** -> ***src*** -> ***JUANITO_APP.h*** \
Enlevez les commentaires devant la ligne : \
`#define DEBUG`

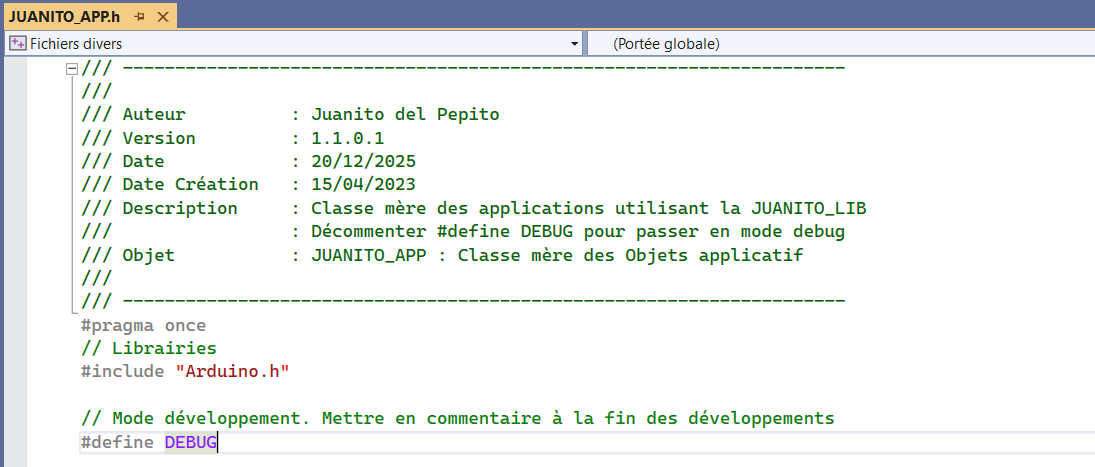
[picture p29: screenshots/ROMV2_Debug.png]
ROMV2 Debug


En activant le mode **Debug**, vous pourrez voir les traces de l'application dans le *Moniteur série* de votre *Arduino IDE* pendant l'exécution. 

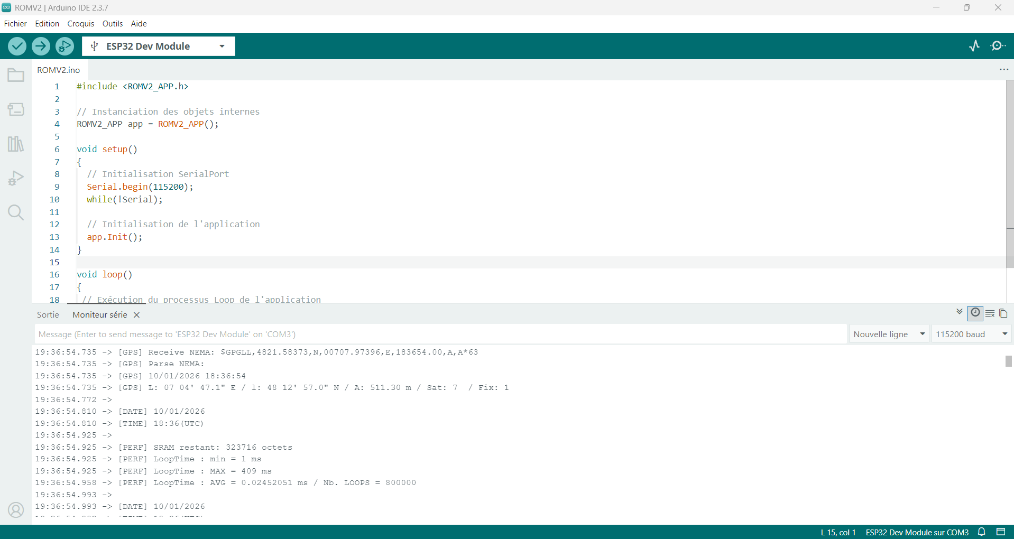
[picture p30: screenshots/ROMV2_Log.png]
ROMV2 Logs


<p align="right"><a href="#sommaire">Retour au sommaire</a></p>

## Utilisation

### Matériel (ROMV2)
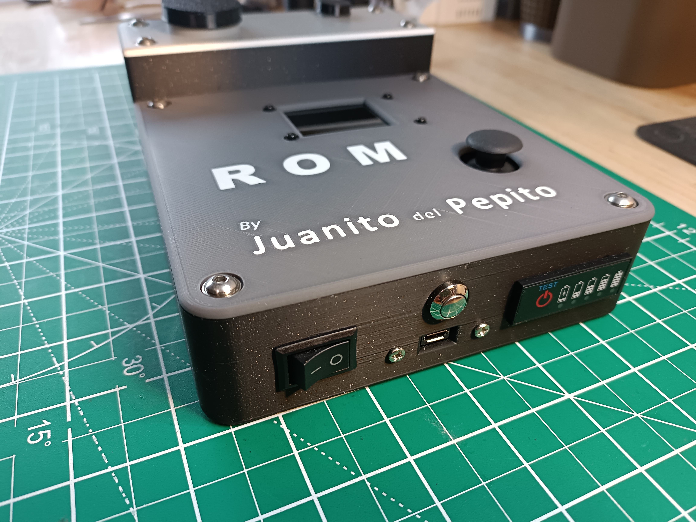
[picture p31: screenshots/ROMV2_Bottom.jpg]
ROMV2 Logs


Vous trouverez au bas du ***ROMV2*** :
- l'interrupteur On/Off de l'appareil.
- 1 connecteur **Micro USB** permettant de recharger le ***ROMV2*** et servant également à la mise à jour du firmware.
- 1 interrupteur (bouton poussoir) permettant de mettre l'ESP en mode Boot lors de la mise à jour du firmware.
- L'indicateur de charge restante dans la batterie. Appuyez sur le bouton **"TEST"** de l'indicateur pour connaître la charge restante.

<p align="right"><a href="#sommaire">Retour au sommaire</a></p>

### Matériel (SQMLite)
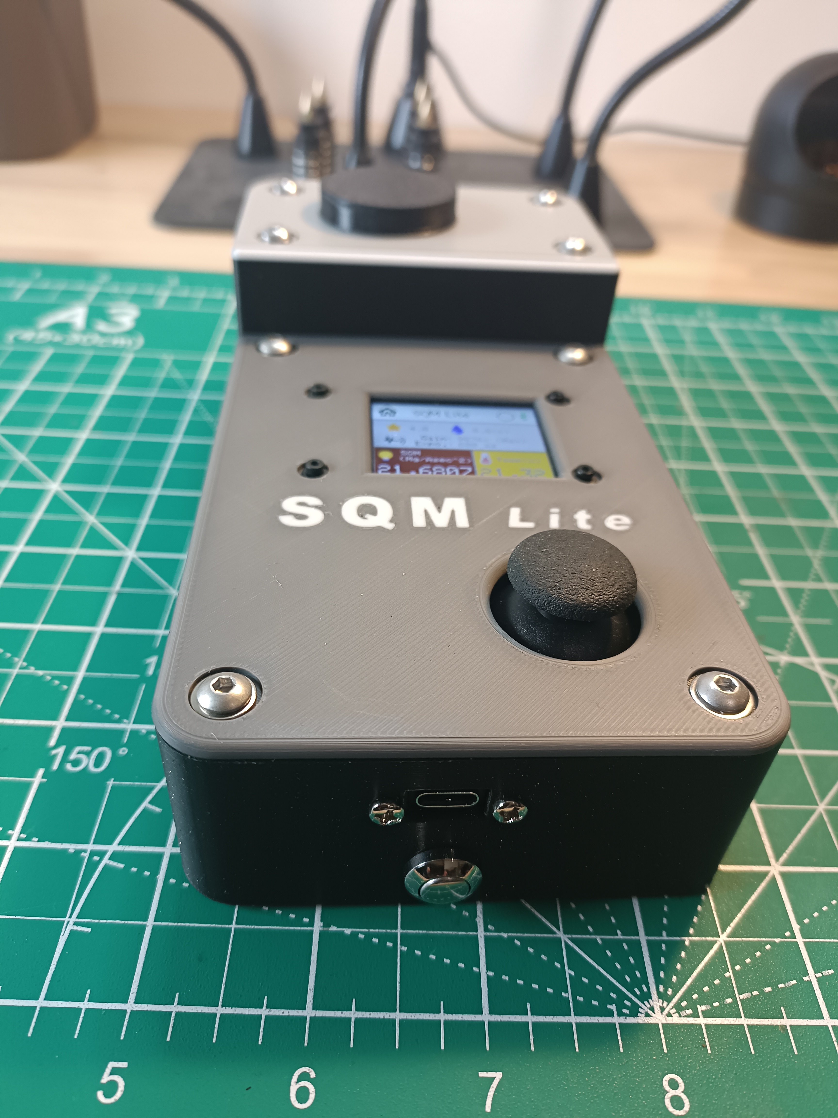
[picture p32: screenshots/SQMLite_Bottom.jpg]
SQMLite Bottom

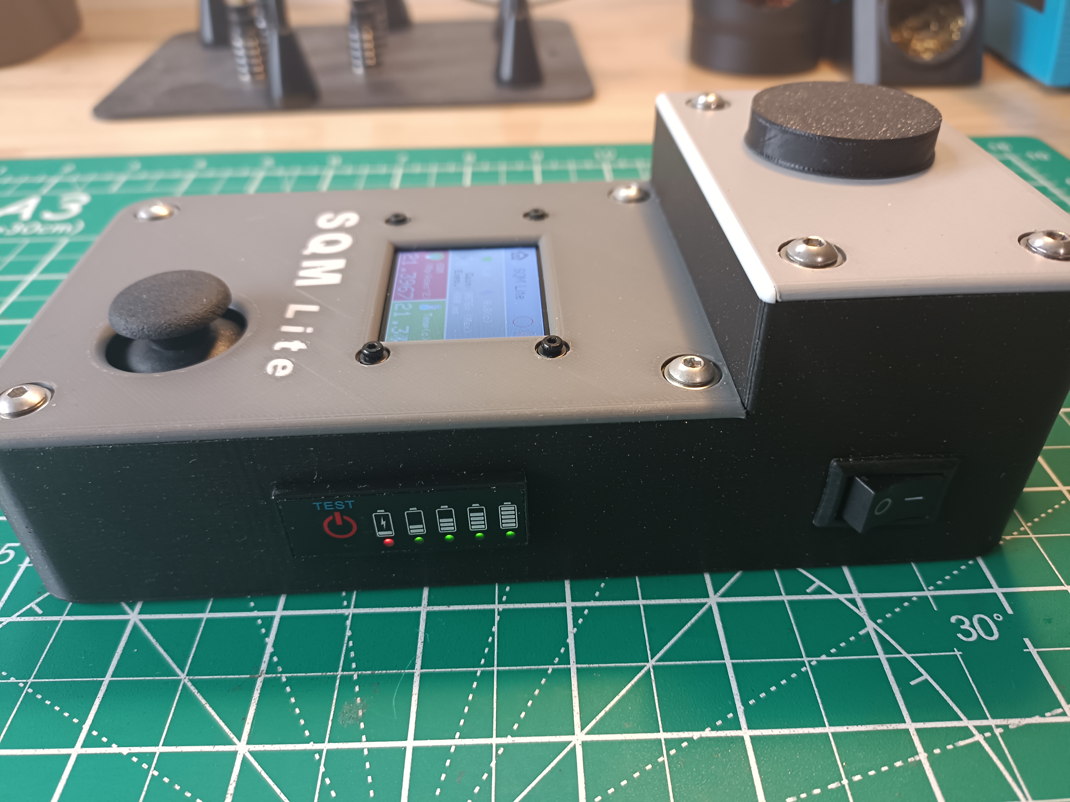
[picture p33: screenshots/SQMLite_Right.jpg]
SQMLite Right


Vous trouverez au bas du ***SQMLite*** :
- 1 connecteur **USB-C** permettant de recharger le ***SQMLite*** et servant également à la mise à jour du firmware.
- 1 interrupteur (bouton poussoir) permettant de mettre l'ESP en mode Boot lors de la mise à jour du firmware.

Vous trouverez sur le côté droit du ***SQMLite*** :
- l'interrupteur On/Off de l'appareil.
- L'indicateur de charge restante dans la batterie. Appuyez sur le bouton **"TEST"** de l'indicateur pour connaître la charge restante.

<p align="right"><a href="#sommaire">Retour au sommaire</a></p>

### Navigation

Le pilotage du ***ROMV2*** et du ***SQMLite*** s'effectue via le joystick :
- Droite et gauche permettent de naviguer parmis les différents écrans.
- Haut et Bas permettent un retour direct à l'écran d'accueil.
- Sur l'écran d'acceuil, un clic sur le joystick permet d'alterner l'affichage Lux et SQM.
- Sur l'écran de luminosité, un clic sur le joystick permet de réinitialiser la moyenne mobile en cours.
- Un clic long sur le joystick permet de basculer l'écran en mode veille.
- Sur l'écran de sélection du réseau, Haut et Bas permettent de modifier le nouveau réseau sélectionné, et un clic sur le joystick permet de sauvegarder la nouvelle valeure du paramètre.
- Sur l'écran de paramétrage du réseau Wifi, un clic sur le joystick permet de passer l'ESP en mode AP (Access Point) ou STA (Station) et inversement. 
- Sur l'écran de calibration du TSL2591, Haut et Bas permettent de modifier la nouvelle valeure de calibration, et un clic sur le joystick permet de sauvegarder la nouvelle valeure du paramètre.

### Mise en veille

L'écran du ***ROMV2*** / ***SQMLite*** s'éteint automatiquement après 5 min d'inactivité (modifiable dans le fichier de configuration).
Cette mise en veille peut être déclenchée à tout moment par un "click long" sur le joystick.

Pour sortir du mode veille, il suffit d'effectuer une action sur le joystick, peu importe laquelle.

<p align="right"><a href="#sommaire">Retour au sommaire</a></p>

### Logiciel

Le firmware est constitué de plusieurs écrans, avec un en-tête commun à tous les écrans.

#### En-tête (ROMV2)

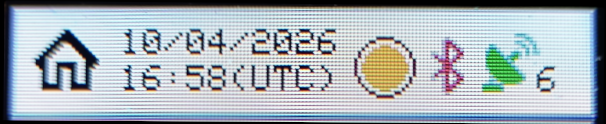
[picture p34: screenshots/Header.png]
Header


L'en-tête comprend les éléments suivants :
- Un icone principal spécifique à l'écran en cours d'affichage.
- La date et l'heure UTC remontée par le capteur GPS.
- Un icone indiquant qu'une prise de mesure de la luminosité est en cours.
- Un icone d'état de la connexion en cours. Trois types d'icone selon la connexion :
    - Icone ***Offline***.
    - Icone ***Bluetooth***. Deux états pour cet icone :
        - Rouge : Aucun client Bluetooth BLE connecté.
        - Vert : Un client BLE est actuellement connecté.
    - Icone ***Wifi***. Quatre état pour cet icone :
        - Rouge : Wifi non connecté.
        - Orange : Connexion en cours OU ESP en mode AP (Access Point).
        - Bleu : Wifi connecté en mode STA (Station) mais aucune connexion avec un Broker MQTT (exple : Mosquito).
        - Vert : Wifi connecté en mode STA (Station) et connexion avec un Broker MQTT effectuée.
- Un icone indiquant si le GPS est "fixé", remontant ainsi les informations de localisation (2 états : rouge et vert). Est également précisé le nombre de satellites à partir desquels le capteur récupère les informations. 

<p align="right"><a href="#sommaire">Retour au sommaire</a></p>

#### En-tête (SQMLite)

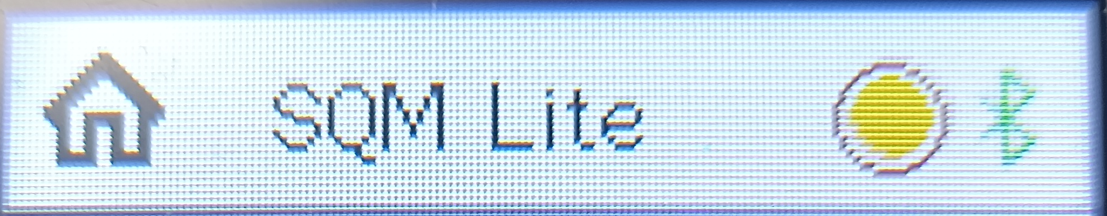
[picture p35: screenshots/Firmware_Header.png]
Header


L'en-tête comprend les éléments suivants :
- Un icone principal spécifique à l'écran en cours d'affichage.
- Le titre de l'application.
- Un icone indiquant qu'une prise de mesure de la luminosité est en cours.
- Un icone d'état de la connexion en cours. Trois types d'icone selon la connexion :
    - Icone ***Offline***.
    - Icone ***Bluetooth***. Deux états pour cet icone :
        - Rouge : Aucun client Bluetooth BLE connecté.
        - Vert : Un client BLE est actuellement connecté.
    - Icone ***Wifi***. Quatre état pour cet icone :
        - Rouge : Wifi non connecté.
        - Orange : Connexion en cours OU ESP en mode AP (Access Point).
        - Bleu : Wifi connecté en mode STA (Station) mais aucune connexion avec un Broker MQTT (exple : Mosquito).
        - Vert : Wifi connecté en mode STA (Station) et connexion avec un Broker MQTT effectuée.

<p align="right"><a href="#sommaire">Retour au sommaire</a></p>

#### Ecran d'accueil

L'écran d'accueil comprend les éléments suivants :
- L'affichage des coordonnées GPS.
- Un icone représentant l'état du ciel. L'icone à trois états : 
    - Ciel clair.
    - Peu nuageux.
    - Nuageux.
- Un icone représentant le point de rosée ainsi que la température du point de rosée. L'icone à trois états :
    - Bleu : pas de risque de buée.
    - Orange : point de rosée à moins de 5°c de la température ambiante, risque de buée imminente.
    - Rouge : point de rosée atteint, pare-buée obligatoire.
- Un icone affichant la valeur de Bortle en cours.
- Un espace affichant la valeur de luminosité mesurée. 2 modes d'affichage :
    - Affichage du Lux
    - Affichage du SQM (Mag / Arcsec²).\
> [!TIP]
> On passe d'un mode à l'autre (Lux / SQM) en cliquant sur le joystick.
- Un espace affichant la valeur de la température ambiante.

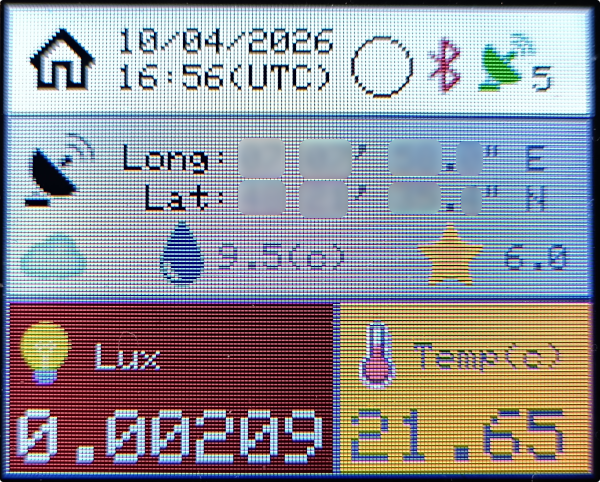
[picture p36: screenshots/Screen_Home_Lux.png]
Screen Home Lux


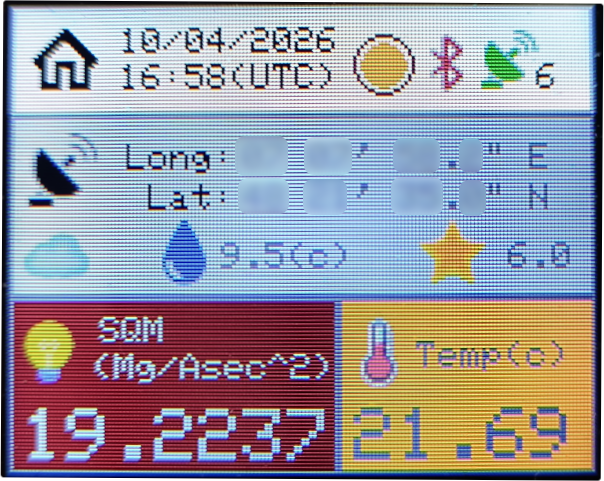
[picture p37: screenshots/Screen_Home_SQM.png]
Screen Home SQM


<p align="right"><a href="#sommaire">Retour au sommaire</a></p>

#### Ecran Luminosité

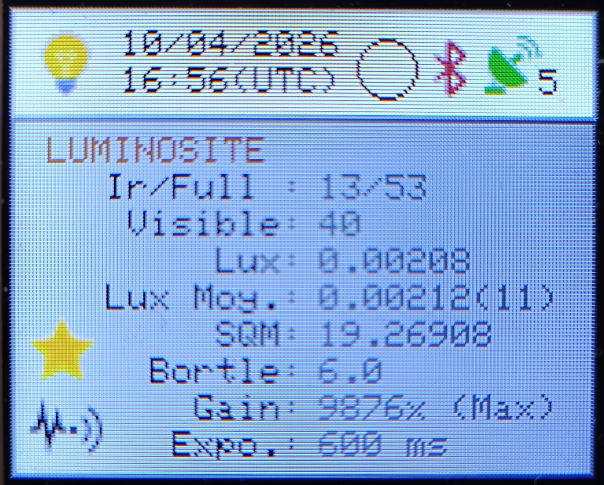
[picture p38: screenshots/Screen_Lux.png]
Screen Lux


L'écran Luminosité comprend les éléments suivants :
- La luminosité mesurée totale et dans les Infrarouge.
- La luminosité mesurée dans le visible.
- La quantité de Lux issue des mesures Ir et Full.
- La quantité de Lux sur une moyenne mobile. Le nombre de mesures permettant de calculer la moyenne est entre parenthèse. Le nombre maximum de valeurs pour le calcul de la moyenne mobile est de 50 (ce nombre est modifiable dans le fichier de configuration via la constante `TSL2591_MOVING_AVERAGE_COUNT`).
- Le SQM (Mag / Arcsec²) calculé à partir du Lux moyen.
- Le Bortle issu de la valeur du SQM calculé.
- Le gain du capteur lors de la dernière mesure de luminosité effectuée.
- Le temps d'exposition du capteur lors de la dernière mesure de luminosité effectuée.

> [!NOTE]
> Le gain et le temps d'exposition du capteur sont ajustés automatiquement par le firmware afin d'avoir les valeurs les plus appropriées en fonction du contexte.

> [!IMPORTANT]
> Pour réinitialiser la moyenne mobile effectuée sur la mesure de Lux, il suffit d'effectuer un **clic sur le joystick**.

<p align="right"><a href="#sommaire">Retour au sommaire</a></p>

#### Ecran Environnement

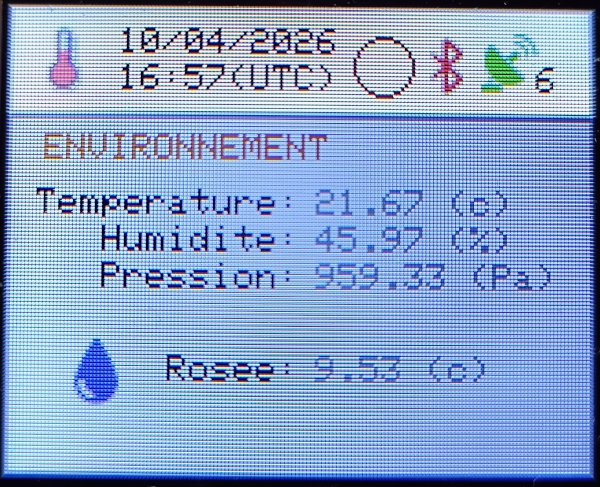
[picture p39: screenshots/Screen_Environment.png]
Screen Lux


L'écran Environnement comprend les éléments suivants :
- La température ambiante (°C).
- Le taux d'humidité (%).
- La pression atmosphérique (Pa).
- Un icone représentant le point de rosée ainsi que la température du point de rosée. L'icone à trois états :
    - Bleu : pas de risque de buée.
    - Orange : point de rosée à moins de 5°c de la température ambiante, risque de buée imminente.
    - Rouge : point de rosée atteint, pare-buée obligatoire.

<p align="right"><a href="#sommaire">Retour au sommaire</a></p>

#### Ecran Ir Température

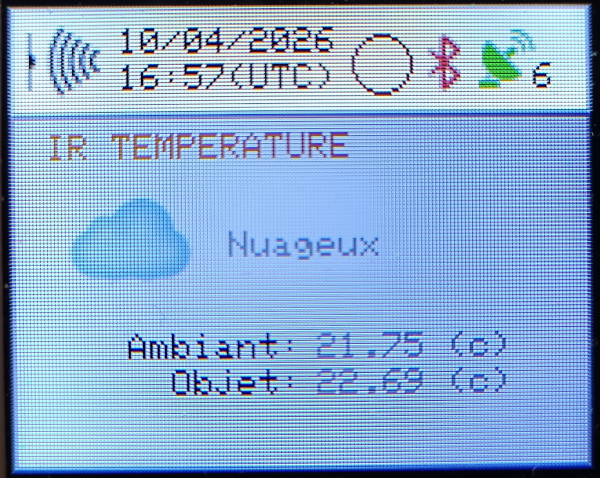
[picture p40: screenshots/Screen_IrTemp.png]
Screen Lux


L'écran Ir Température permet d'afficher l'état du ciel. Il comprend les éléments suivants :
- Un icone représentant l'état du ciel. L'icone à trois états : 
    - Ciel clair.\
    Sky State Clear
    - Peu nuageux.\
    Sky State Partly Cloudy
    - Nuageux.\
    Sky State Cloudy
- La température ambiante mesurée.
- La température de l'objet mesurée.

<p align="right"><a href="#sommaire">Retour au sommaire</a></p>

#### Ecran Niveaux

Screen Lux

L'écran Niveaux permet d'afficher un niveau à bulle afin de positionner correctement le capteur de luminosité au zénith. Il comprend les éléments suivants :
- Un niveau à bulle de forme circulaire.
- L'accélération en X (m / s²).
- L'accélération en Y (m / s²).
- L'accélération en Z (m / s²).

<p align="right"><a href="#sommaire">Retour au sommaire</a></p>

#### Ecran GPS

Screen Lux

L'écran GPS permet d'afficher les données issues du GPS. Il comprend les éléments suivants :
- Les coordonnées longitude et latitude en degrés, minutes, secondes et dizaines de secondes, orientation.
- Le nombre de satellites à partir desquels le capteur GPS récupère les informations.
- L'état "fixé" ou non.
- L'altitude courante (m).

<p align="right"><a href="#sommaire">Retour au sommaire</a></p>

#### Ecran de calibration du capteur de luminosité TSL2591

Screen Calibration TSL2591

L'écran de calibration du capteur de luminosité TSL2591 permet de définir de calibration qui sera utilisée lors du calcul du SQM (et du Bortle). Il comprend les éléments suivants :
- La valeur actuelle.
- La nouvelle valeur à enregistrer en EEPROM.

> [!NOTE]
> Vous pouvez modifier cette valeur grâce au joystick :
>- Un mouvement court vers le haut incrémente la valeur de 0.01.
>- Un mouvement long vers le haut augmente rapidement la valeur.
>- Un mouvement court vers le bas décrémente la valeur de 0.01.
>- Un mouvement long vers le haut diminue rapidement la valeur.
>- Un clic sur le joystick permet l'enregistrement de cette nouvelle valeur en EEPROM.

<p align="right"><a href="#sommaire">Retour au sommaire</a></p>

## Driver ASCOM

Driver Setup Dialog

### Installation

- Téléchargez et exécutez le fichier **RemoteOpenMeteoV2-SQM Setup.exe**

Driver Installer screen 1

Driver Installer screen 2

Driver Installer screen 3

<p align="right"><a href="#sommaire">Retour au sommaire</a></p>

### Détection du périphérique bluetooth dans Windows

Afin de pouvoir utiliser le Driver ASCOM ROM V2 - SQM depuis votre application Astro comme N.I.N.A., vous devez au préalable déclarer votre périphérique Bluetooth auprès de votre système Windows.

> [!IMPORTANT]
> Cette opération de reconnaissance de votre périphérique Bluetooth auprès de votre système Windows n'est à faire qu'une seule fois, lors de la première utilisation.

Windows bluetooth

Dans la fenêtre des paramètres windows, allez dans la section "***Bluetooth et appareils***", si nécessaire, cliquez sur "***Afficher d'autres périphériques***", puis cliquez sur le bouton "***Ajouter un appareil***" et suivez les étapes de l'assistant.

<p align="right"><a href="#sommaire">Retour au sommaire</a></p>

### Utilisation dans NINA

NINA

#### Sélection du ROM V2 dans NINA

Afin de sélectionner le ROM V2 - SQM dans N.I.N.A., allez dans l'onglet "***Equipements***", et dans le sous-onglet "***Météo***".\
Dans la liste déroulante, sélectionnez "***ROM V2 - Sky Quality Meter***"

NINA Sélection ROM

<p align="right"><a href="#sommaire">Retour au sommaire</a></p>

#### Première utilisation dans NINA

Lors de la première utilisation dans N.I.N.A., un appairage du ROM V2 - SQM est nécessaire.\
Pour cela, cliquez sur le bouton "***Paramètres***".

NINA ROM settings

Dans la boîte de dialogue qui s'ouvre, sélectionnez le périphérique "***REMOTE OPEN METEO***" détecté puis validez.

Driver Setup Dialog

> [!NOTE]
> Voilà, l'appairage est effectué. Il ne sera plus nécessaire d'effectuer cette opération lors des prochaines utilisations.

<p align="right"><a href="#sommaire">Retour au sommaire</a></p>

Voilà, vous pouvez désormais profiter des données du ROM V2 - SQM dans NINA.\
Enjoy

NINA démo

<p align="right"><b><i>Juanito del Pepito</i></b></p>

## Retex

Voici un petit retour d'expérience des mesures de l'état de mon ciel à mon domicile :

NINA démo

## Révisions

| Date | Version | Commentaires |
| --- | --- | --- |
| 27/05/2026 | 2.0.3.1 | <ul><li>Ajout d'un nouvel écran permettant la calibration du capteur de luminosité TSL2591.</li><li>Sauvegarde et lecture de la calibration en EEPROM permettant de stocker cette valeur même après extinction de l'appareil.</ul> |
| 23/05/2026 | 2.0.2.1 | Correction thermique de la lecture de la luminosité avec la température ambiante. |
| 17/05/2026 | 2.0.1.2 | Simplification du train optique du TSL2591. |
| 08/05/2026 | 2.0.1.1 | Lecture de la luminosité dans une tâche dédiée FreeRTOS s'exécutant en paralèlle sur le 2ème coeur de l'ESP 32. |
| 30/04/2026 | 2.0.0.1 | Version initiale. |

<p align="right"><a href="#sommaire">Retour au sommaire</a></p>

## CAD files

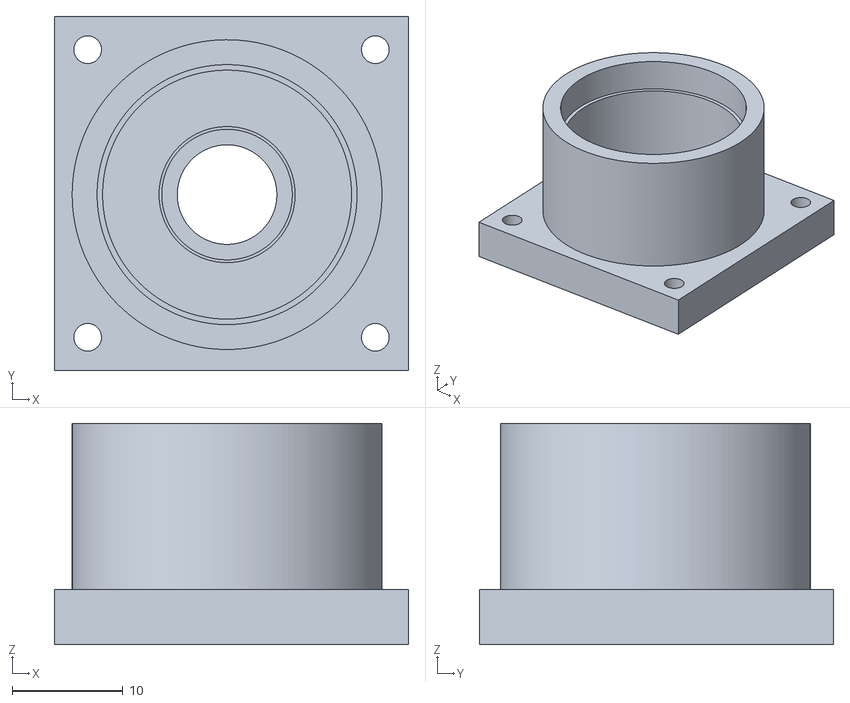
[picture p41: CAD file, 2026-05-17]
Boxes/ROMV2_TSL2591_Enclosure.stl
32.0 x 32.0 x 20.0

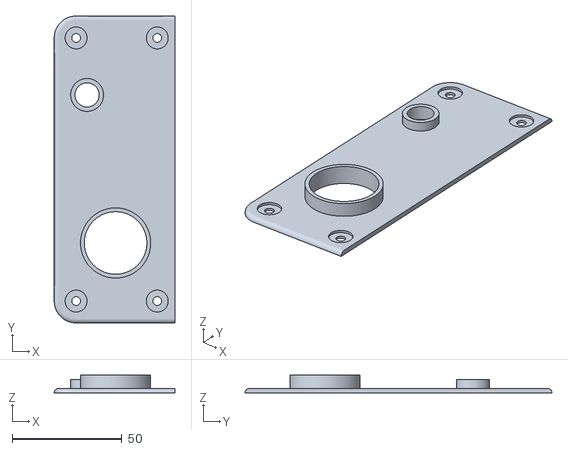
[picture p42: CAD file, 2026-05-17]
Boxes/ROMV2_TopHigh.stl
55.0 x 140.0 x 8.00

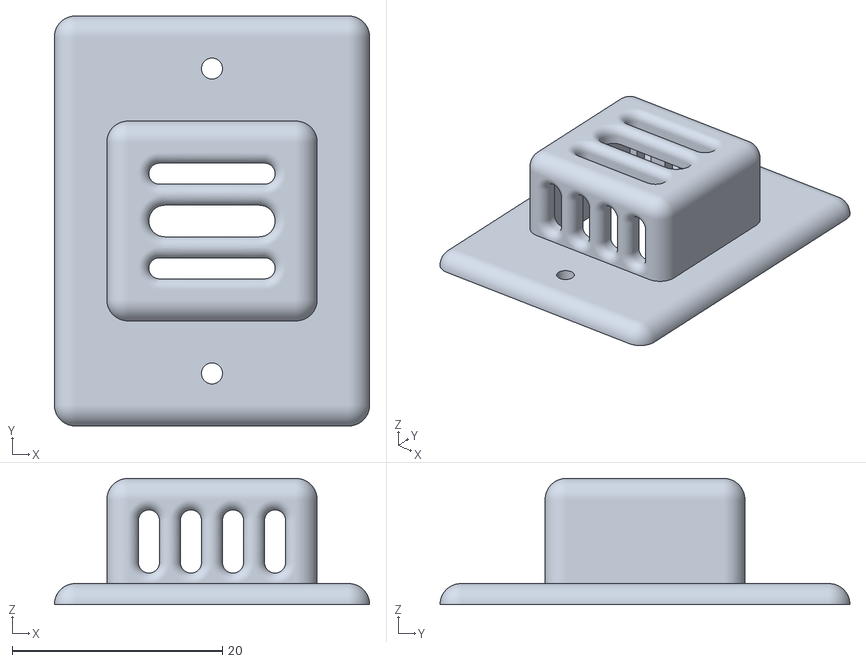
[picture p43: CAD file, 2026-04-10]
Boxes/ROMV2_Sensor.stl
30.0 x 39.0 x 12.0

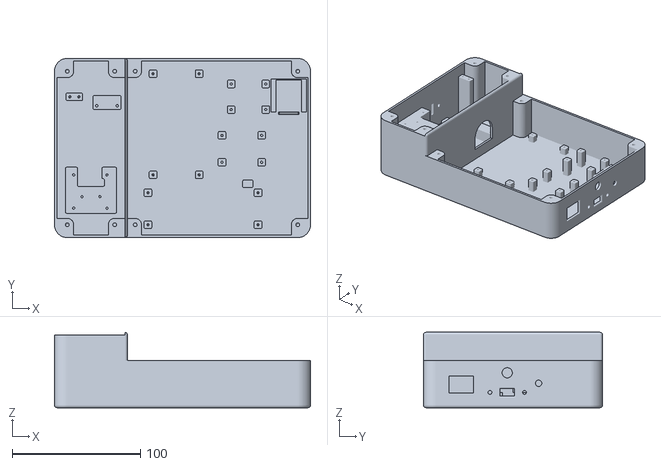
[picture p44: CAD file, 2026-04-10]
Boxes/ROMV2_Bottom.stl
200.0 x 140.0 x 59.0

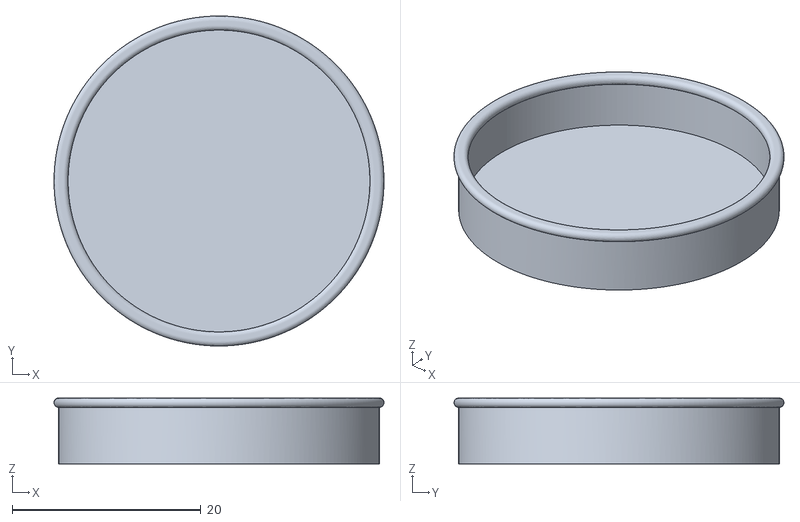
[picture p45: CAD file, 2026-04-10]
Boxes/ROMV2_Tube28_Cover_TPU.stl
35.0 x 35.0 x 7.00

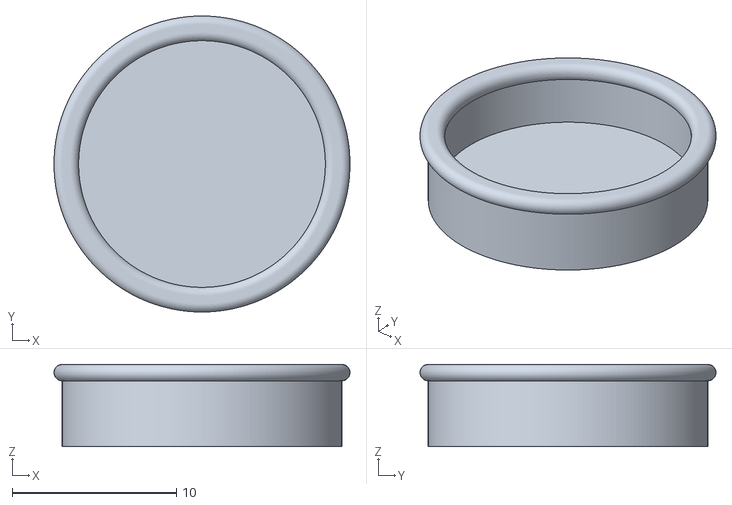
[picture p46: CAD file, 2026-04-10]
Boxes/ROMV2_Tube15_Cover_TPU.stl
18.0 x 18.0 x 5.00

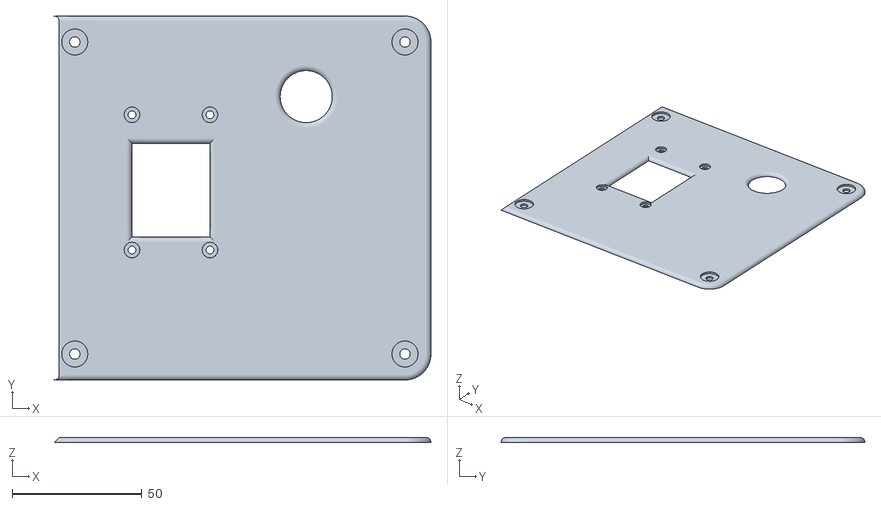
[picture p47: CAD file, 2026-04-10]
Boxes/ROMV2_TopLow.stl
145.0 x 140.0 x 2.00

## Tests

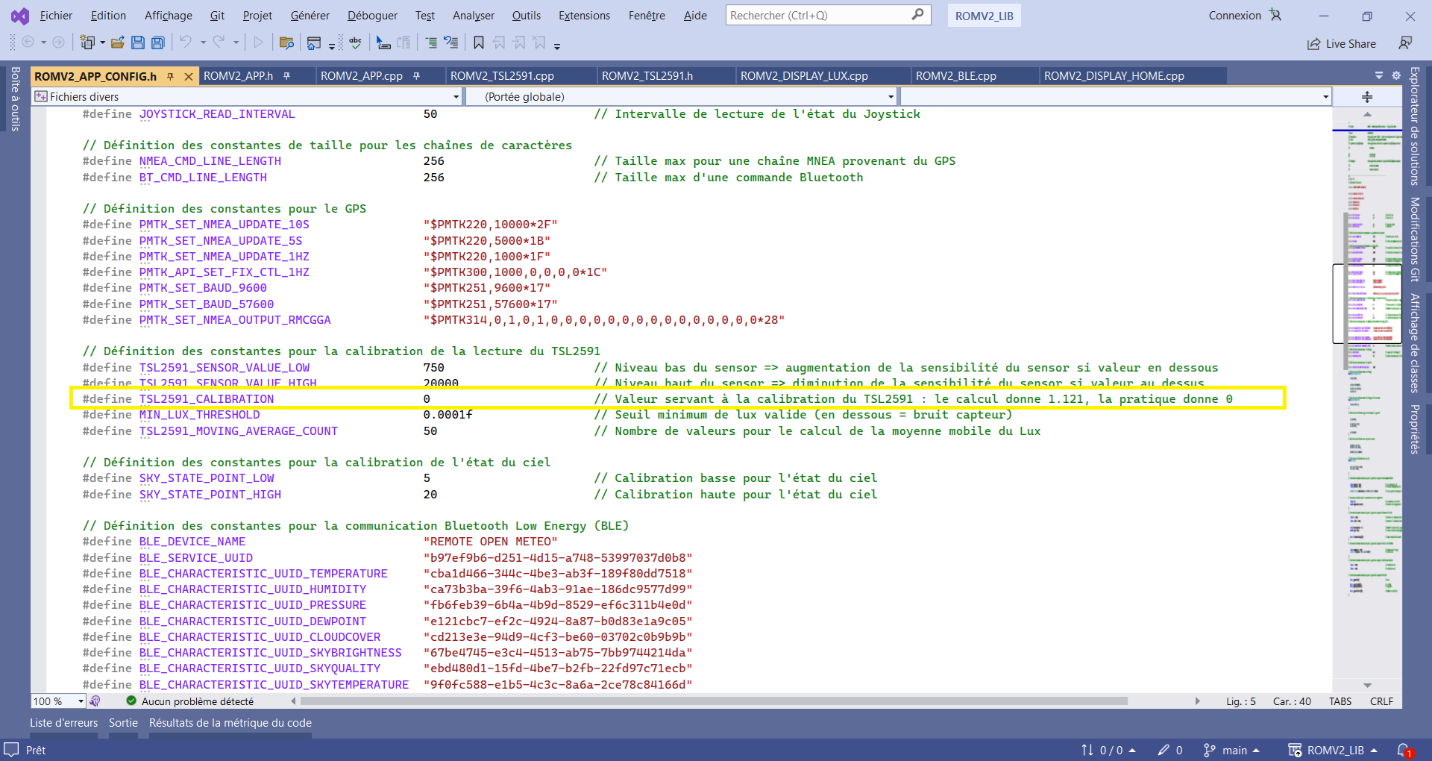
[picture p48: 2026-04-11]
screenshots/Calibration.png

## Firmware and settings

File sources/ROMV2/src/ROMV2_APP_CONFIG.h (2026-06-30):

/// ---------------------------------------------------------------------
///
/// Projet                          : ROMV2 - Remote Open Météo Version 2 - Sky Quality Meter DIY
/// Auteur                          : Juanito del Pepito
/// Version                         : 2.1.0.1
/// Date                            : 10/04/2026
/// Date Révision                   : 27/06/2026
/// 
/// Description                     : Sky Quality Meter (SQM) - Fichier de configuration de l'application
/// Gitub                           : https://github.com/Juani005999/ROMV2
/// Licence							: GPL-3.0 license
///
/// Capteurs et périphériques       : Cette application utilise les capteurs et périphériques suivant
///										- TSL2591
///										- MLX90614
///										- BME280
///										- ADXL345
///										- GPS NEO 8M
///										- TFT ST7735
/// 
/// Prérequis                       : Cette application nécessite l'ajout des bibliothèques suivantes
///										- Adafruit_TSL2591
///										- Adafruit_MLX90614
///										- Adafruit_BME280
///										- Adafruit_ADXL345
///										- TFT_eSPI
/// 
/// ---------------------------------------------------------------------
#pragma once

// Include des librairies
#include "JUANITO_APP.h"
#include "JUANITO_MOVING_AVERAGE.h"
#include <ROMV2_APP_ICONS.h>
#include <ROMV2_I2C.h>
#include <Adafruit_BME280.h>
#include <Adafruit_TSL2591.h>
#include <Adafruit_MLX90614.h>
#include <Adafruit_ADXL345_U.h>
#include <TFT_eSPI.h>
#include <BLEDevice.h>
#include <BLEServer.h>
#include <BLEUtils.h>
#include <BLE2902.h>
#include <Preferences.h>
#include <WiFi.h>
#include <PubSubClient.h>

// Définition des constantes correspondant aux PIN
#define ESP32_GPIO_SDA								21                  // GPIO I2C SDA
#define ESP32_GPIO_SCL								22                  // GPIO I2C SCL
#define GPS_RX										17					// RX pour le Serial du GPS
#define GPS_TX										16					// TX pour le Serial du GPS
#define JOYSTICK_PIN_SWITCH							25                  // Joystick Switch
#define JOYSTICK_PIN_X								32                  // Joystick X
#define JOYSTICK_PIN_Y								33                  // Joystick Y

// Définition des constantes correspondant aux paramètres des capteurs
#define BME280_I2C_ADDRESS							0x76                // Sensor T/P/H BME280
#define TSL2591_NUMBER_ID							2591                // Identifiant du TSL2591
#define ADXL345_NUMBER_ID							7112                // Identifiant du ADXL345
#define GPS_BAUD									9600				// Vitesse de communication sur le port série du GPS

// Définition des constantes correspondant aux intervalles
#define READ_ENVIRONMENT_INTERVAL					3000                // Intervalle de lecture de l'environnement via BME280
#define READ_LUX_INTERVAL							2000				// Intervalle de lecture de la luminosité via TSL2591
#define READ_IRTEMP_INTERVAL						2000                // Intervalle de lecture de la température IR via MLX90614
#define READ_ACCEL_INTERVAL							120					// Intervalle de lecture de l'accélération via ADXL345
#define READ_GPS_STATE_INTERVAL						5000				// Intervalle de lecture de l'état du GPS
#define BLE_NOTIFY_INTERVAL							1000				// Intervalle de Notification des caractéristiques BLE (Bluetooth Low Energy)
#define BLE_ADVERTISING_RESTART_DELAY				500					// Délai avant relance de l'advertising après déconnexion (laisse la stack BLE se stabiliser)
#define DISPLAY_INTERVAL							120                 // Intervalle d'affichage sur l'écran
#define JOYSTICK_BUTTON_LONG_INTERVAL				1000				// Intervalle du clic long sur le Joystick
#define JOYSTICK_MOVE_LONG_INTERVAL					500					// Intervalle du mouvement long sur le Joystick
#define JOYSTICK_READ_INTERVAL						50					// Intervalle de lecture de l'état du Joystick
#define WIFI_LOOP_INTERVAL							500                 // Intervalle de traitement du loop WiFi (ms)
#define WIFI_CHECKSTATE_INTERVAL					200					// Interval de vérification de l'état du Wifi (ms)
#define MQTT_RECONNECT_INTERVAL						10000				// Interval entre deux tentatives de reconnexion MQTT
#define MQTT_PUBLISH_INTERVAL						10000               // Intervalle de publication MQTT (ms)
#define MQTT_LOOP_INTERVAL							200                 // Intervalle de traitement du loop MQTT (ms)

// Définition des constantes de taille pour les chaînes de caractères
#define NMEA_CMD_LINE_LENGTH						256                 // Taille max pour une chaîne MNEA provenant du GPS
#define BT_CMD_LINE_LENGTH							256                 // Taille max d'une commande Bluetooth

// Définition des constantes pour le GPS
#define PMTK_SET_NMEA_UPDATE_10S					"$PMTK220,10000*2F"
#define PMTK_SET_NMEA_UPDATE_5S						"$PMTK220,5000*1B"
#define PMTK_SET_NMEA_UPDATE_1HZ					"$PMTK220,1000*1F"
#define PMTK_API_SET_FIX_CTL_1HZ					"$PMTK300,1000,0,0,0,0*1C"
#define PMTK_SET_BAUD_9600							"$PMTK251,9600*17"
#define PMTK_SET_BAUD_57600							"$PMTK251,57600*17"
#define PMTK_SET_NMEA_OUTPUT_RMCGGA					"$PMTK314,0,1,0,1,0,0,0,0,0,0,0,0,0,0,0,0,0,0,0*28"
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

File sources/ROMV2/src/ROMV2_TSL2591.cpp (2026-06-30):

#include <ROMV2_TSL2591.h>

/// <summary>
/// Constructeur
/// </summary>
ROMV2_TSL2591::ROMV2_TSL2591()
{
}

/// <summary>
/// Initialisation
/// </summary>
/// <param name="tft"></param>
/// <param name="dataLuminosity"></param>
/// <param name="dataEnvironment"></param>
void ROMV2_TSL2591::Init(ROMV2_TFT_COMMON* tft, DataSensorLuminosity* dataLuminosity, DataSensorEnvironment* dataEnvironment)
{
    // Valorisation des membres internes
    _tft = tft;
    _dataLuminosity = dataLuminosity;
    _dataEnvironment = dataEnvironment;

    // Création du mutex FreeRTOS
    _mutex = xSemaphoreCreateMutex();

    // Initialisation TSL2591
    if (!_tsl2591.begin()) {
        debugln(F("Could not find a valid TSL2591 sensor, check wiring!"));
        while (1);
    }

    // Configuration du capteur
    DisplaySensorDetails();
    ConfigureSensor();

    // Initialisation des chronos
    _chronoDisplayLux = 0;
}

/// <summary>
/// Démarre la tâche FreeRTOS sur le coeur 0
/// </summary>
void ROMV2_TSL2591::StartTask()
{
    // Trace
    debugln(F(""));
    debugln(F("[LUX] Starting ROMV2_TSL2591 TaskLoop"));

    xTaskCreatePinnedToCore(
        TaskWrapper,    // Fonction statique wrapper
        "TSL2591",      // Nom de la tâche
        4096,           // Stack en bytes (augmenter à 8192 si stack overflow)
        this,           // Passage du pointeur this pour accéder aux membres
        1,              // Priorité
        NULL,           // Handle (non utilisé)
        0               // Coeur 0 -> laisse le coeur 1 libre pour l'UI
    );

    // Trace
    debugln(F("[LUX] ROMV2_TSL2591 TaskLoop Started"));
}

/// <summary>
/// Wrapper statique requis par FreeRTOS — redirige vers TaskLoop()
/// </summary>
void ROMV2_TSL2591::TaskWrapper(void* pvParameters)
{
    // pvParameters contient le pointeur this passé dans StartTask()
    static_cast<ROMV2_TSL2591*>(pvParameters)->TaskLoop();
}

/// <summary>
/// Boucle de la tâche FreeRTOS — tourne en continu sur le coeur 0
/// </summary>
void ROMV2_TSL2591::TaskLoop()
{
    while (true)
    {
        // Lecture suspendue (ex. écran niveau à bulle) : on ne touche PAS au bus I2C,
        // on se contente de re-tester le drapeau périodiquement.
        if (_readingPaused)
        {
            _luminosityIconOn = false;
            vTaskDelay(pdMS_TO_TICKS(100));
            continue;
        }

        // Lecture des données brutes du capteur
        _luminosityIconOn = true;

        // Lecture des données sous mutex I2C
        uint32_t lum = 0;
        bool luxRead = false;
        {
            // Timeout généreux : le TSL ne lit que toutes les 2 s, il peut attendre le bus
            I2CLock lock(pdMS_TO_TICKS(300));
            if (lock.ok())
            {
                lum = _tsl2591.getFullLuminosity();
                luxRead = true;
            }
        }   // verrou I2C rendu ICI

        // Si le bus était occupé, on saute ce cycle (les dernières valeurs sont conservées)
        if (luxRead)
        {
            uint16_t ir = lum >> 16;
            uint16_t full = lum & 0xFFFF;
            uint16_t visible = full - ir;
            float    lux = _tsl2591.calculateLux(full, ir);

            // Ecriture des données sous mutex OBJET (distinct du verrou I2C)
            if (xSemaphoreTake(_mutex, pdMS_TO_TICKS(50)) == pdTRUE)
            {
                _lastIrRead = ir;
                _lastFullRead = full;
                _lastVisibleRead = visible;
                _lastLuxRead = lux;
                _newDataReady = true;

                // On libère le mutex
                xSemaphoreGive(_mutex);
            }

            // Traces
            debugln(F(""));
            debugln(F("[LUX] Lecture du TSL2591 dans TaskLoop"));
            debug(F("[LUX] IR: "));
            debugln(ir);
            debug(F("[LUX] Full: "));
            debugln(full);
            debug(F("[LUX] Visible: "));
            debugln(visible);
            debug(F("[LUX] Lux: "));
            debugln(lux);
        }
        else
        {
            // Traces
            debugln(F(""));
            debugln(F("[LUX] Lecture du TSL2591 dans TaskLoop"));
            debugln(F("[LUX] Mutex I2C déjà occupé"));
            debugln(F("[LUX] Pas de lecture sur ce cycle"));
        }

        // On repositionne l'icone de lecture d'état
        _luminosityIconOn = false;

        // Libère le CPU pendant le temps d'intégration
        // => le coeur 0 est entièrement libre pendant cette attente
        vTaskDelay(pdMS_TO_TICKS(READ_LUX_INTERVAL));
    }
}

/// <summary>
/// Lecture de la Luminosité
/// </summary>
void ROMV2_TSL2591::ReadLuminosity()
{
    // Lecture de luminosité sur intervalle
    if (millis() - _chronoDisplayLux >= DISPLAY_INTERVAL)
    {
        // Gestion icône — exécuté sur cœur 1, donc TFT safe
        _tft->SetLuminosityIcon(_luminosityIconOn);

        // On récupère dans le Thread principal les valeurs lues dans le Thread 1
        if (xSemaphoreTake(_mutex, pdMS_TO_TICKS(10)) == pdTRUE)
        {
            if (_newDataReady)
            {
                // Mise à jour des données sous mutex
                _localIr = _lastIrRead;
                _localFull = _lastFullRead;
                _localVisible = _lastVisibleRead;
                _localLux = _lastLuxRead;
                _newDataReady = false;
                _updatedData = true;
            }

            // On libère le mutex
            xSemaphoreGive(_mutex);
        }

        if (_updatedData)
        {
            // Mise à jour des données globale
            _dataLuminosity->ir = _localIr;
            _dataLuminosity->full = _localFull;
            _dataLuminosity->visible = _localVisible;
            _dataLuminosity->lux = _localLux;

            // Correction thermique du lux mesuré
            _dataLuminosity->luxThermalCorrected = CorrectThermal(_dataLuminosity->lux);

            // Ajout dans la moyenne mobile si valeurs valides
            if (!isnan(_dataLuminosity->luxThermalCorrected) && !isinf(_dataLuminosity->luxThermalCorrected)
                && _dataLuminosity->luxThermalCorrected > MIN_LUX_THRESHOLD
                && _dataLuminosity->full != 0xFFFF && _dataLuminosity->ir != 0xFFFF)
            {
                // On ajoute à la queue et on récupère la moyenne et la taille
                _luxAverageQueue.Push(_dataLuminosity->luxThermalCorrected);
                _luxAverageQueue.Average(_dataLuminosity->luxAverage);
                _dataLuminosity->luxAverageCount = _luxAverageQueue.Size();
            }

            // Update de la valeur de SQM et de Bortle en fonction des valeurs mesurées
            UpdateSQM();
            UpdateBortle();
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

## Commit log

2026-04-10 Readme MD
    [ROMV2_Bottom.stl, ROMV2_Sensor.stl, ROMV2_TSL2591_Enclosure.stl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]
2026-04-12 Upload ASCOM Driver and update Firmware
2026-05-08 Lecture de la luminosité dans une tâche FreeRTOS
2026-05-17 Simplification du train optique du TSL2591
    [ROMV2_TSL2591_Enclosure.stl, ROMV2_TSL2591_Tube_28x10.stl, ROMV2_TopHigh.stl]
2026-05-18 Update des liens de pièces
2026-05-22 Correction thermique du Lux
    [ROMV2.ino, ROMV2_APP.cpp, ROMV2_APP_CONFIG.h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]
2026-05-27 Ajout écran Calibration TSL2591 et Sauvegarde de la calibration en EEPROM
